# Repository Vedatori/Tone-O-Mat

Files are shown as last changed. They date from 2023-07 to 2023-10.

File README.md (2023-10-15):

# Tone-O-Mat V2.0 [cz]
Tone-O-Mat je analogový syntetizátor vytvořený pro Letní robotický tábor 2023 organizovaný spolkem Vědátoři. Jedná se o stavebnici založenou na 555 timeru určenou pro vzdělávání v oblasti STEM s reproduktorem nebo výstupem pro audio-jack. Stavebnice se skládá ze dvou hlavních částí - plošného spoje osazeného elektronickými součástkami a dřevěné krabičky. Tuto stavebnici účastníci tábora obdrželi k montáži. Hlavním cílem bylo zdokonalit dovednosti pájení a zručnost v práci se dřevem. Z připravených dřevěných dílů si účastníci sami sestavili a slepili krabičku. Poté se pustili do pájení všech součástek na plošný spoj. Měli možnost volit mezi tradičním pájením THT a náročnějším zapájením SMD součástek. Tento projekt byl koncipován tak, aby byl přístupný jak úplným začátečníkům v pájení, tak i těm s více zkušenostmi. Po dokončení stavebnice mohli účastníci na syntetizátoru hrát jako na malém klavírku.

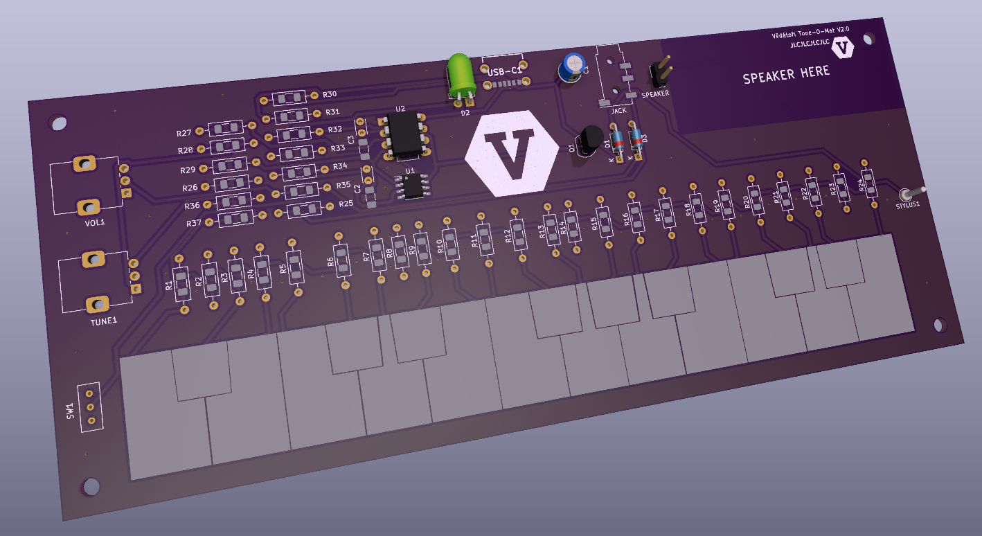
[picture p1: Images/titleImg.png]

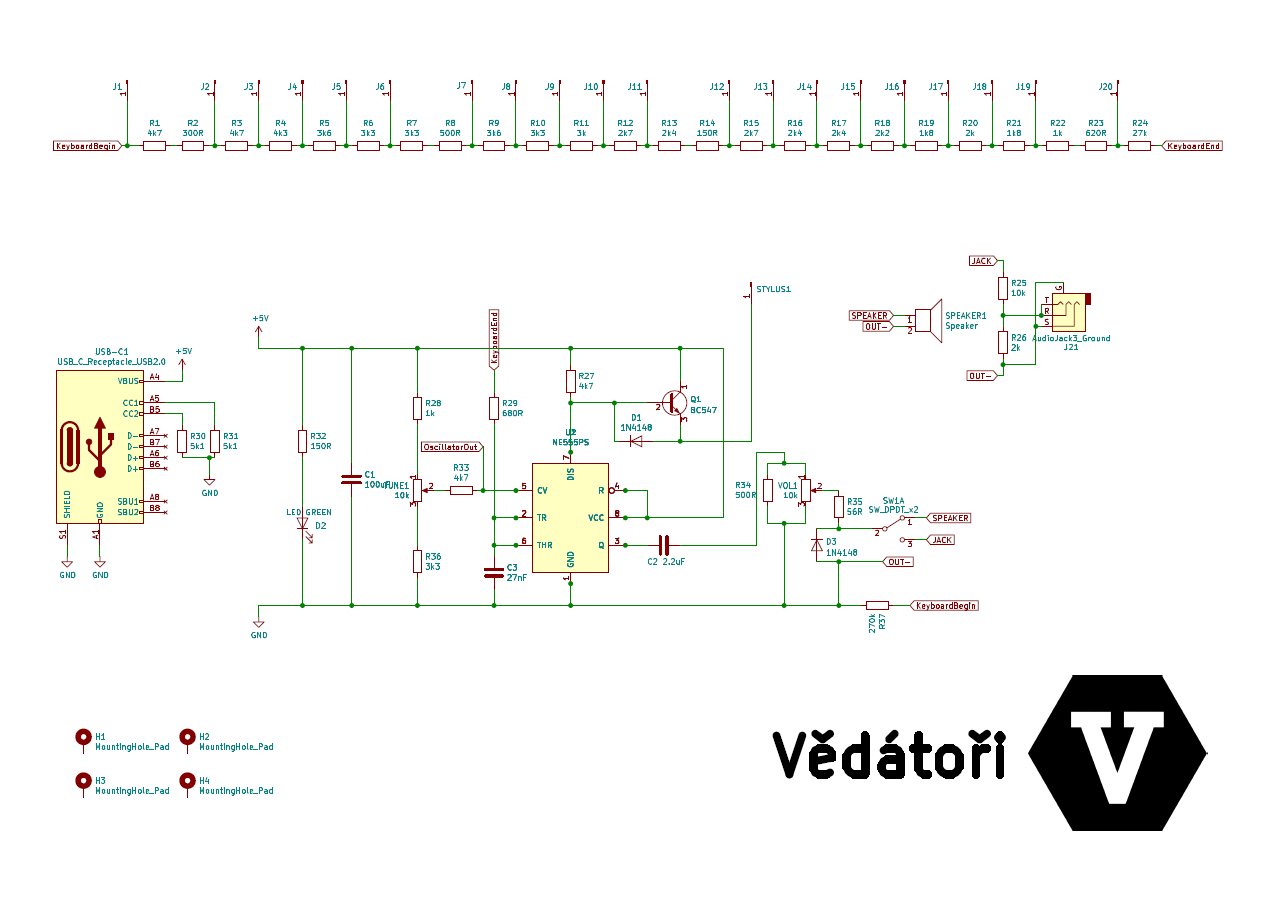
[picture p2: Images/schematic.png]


# Tone-O-Mat V2.0 [en]
Tone-O-Mat is an analog tone synthesizer designed for Summer robotics camp 2023 (cz) organized by Vědátoři team (cz). It is an electronic kit based on a 555 timer meant for STEM education, with speaker or audio-jack output. It is composed of two main parts - a printed circuit board with electronic components and a wooden enclosure. Participants at the camp received this kit for assembly. The primary objective was to enhance soldering skills and proficiency in working with wood. From the pre-cut wooden pieces, participants assembled and glued the enclosure themselves. They then proceeded to solder all the components onto the printed circuit board. They had the option to choose between traditional THT soldering and the more challenging SMD soldering. This project was designed to be accessible to both complete beginners in soldering and those with more experience. Upon completing the assembly, participants could play the synthesizer as a miniature keyboard.

## Licence
* Obsah tohoto repozitáře je sdílen pod licencí [Attribution-NonCommercial-ShareAlike 4.0 International (CC BY-NC-SA 4.0)](https://creativecommons.org/licenses/by-nc-sa/4.0/).

## License
* The contents of this repository are shared under the license [Attribution-NonCommercial-ShareAlike 4.0 International (CC BY-NC-SA 4.0)](https://creativecommons.org/licenses/by-nc-sa/4.0/).

## Source
The schematic was customised from the schematic found at https://gr33nonline.wordpress.com/2018/04/25/stylophone/

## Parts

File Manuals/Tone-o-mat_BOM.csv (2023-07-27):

Designator | Footprint | Quantity | Value | LCSC Part #
C1, C3, C5 | 1206 | 3 | 0.1uF
C10 | C_Disc_D3.0mm_W2.0mm_P2.50mm | 1 | 2.2uF
C11 | 1206 | 1 | 2.2uF
C12 | C_Disc_D3.0mm_W2.0mm_P2.50mm | 1 | 27nF
C13 | 1206 | 1 | 27nF
C2, C4, C6 | C_Disc_D3.0mm_W2.0mm_P2.50mm | 3 | 0.1uF
C7 | 1206 | 1 | 10uF
C8 | C_Disc_D3.0mm_W2.0mm_P2.50mm | 1 | 10uF
C9 | CP_Radial_D5.0mm_P2.00mm | 1 | 100uF
D1, D3 | D_DO-35_SOD27_P7.62mm_Horizontal | 2 | 1N4148
D2 | LED_D5.0mm_Horizontal_O1.27mm_Z3.0mm | 1 | LED GREEN
G1 | Vedatori_logo | 1 | LOGO
G2 | Vedatori_logo_small | 1 | LOGO
H1, H2, H3 | MountingHole_3.2mm_M3_DIN965 | 3 | MountingHole_Pad
J1, J16, J4, J9 | Tone-O-Mat-Left-Pad | 4 | Conn_01x01_Male
J10, J12, J14, J17, J19, J2, J5, J7 | Tone-O-Mat-Top-Pad | 8 | Conn_01x01_Male
J11, J13, J18, J6 | Tone-O-Mat-Middle-Pad | 4 | Conn_01x01_Male
J15, J20, J3, J8 | Tone-O-Mat-Right-Pad | 4 | Conn_01x01_Male
Q1, Q2 | TO-92_Inline | 2 | BC547
R1, R49, R5, R59, R73 | 1206 | 5 | 4k7
R10, R18 | R_Axial_DIN0207_L6.3mm_D2.5mm_P10.16mm_Horizontal | 2 | 3k6
R11, R13, R19, R53, R55, R79 | 1206 | 6 | 3k3
R12, R14, R20, R54, R56, R80 | R_Axial_DIN0207_L6.3mm_D2.5mm_P10.16mm_Horizontal | 6 | 3k3
R15 | 1206 | 1 | 499R
R16 | R_Axial_DIN0207_L6.3mm_D2.5mm_P10.16mm_Horizontal | 1 | 499R
R17, R9 | 1206 | 2 | 3k6
R2, R50, R6, R60, R74 | R_Axial_DIN0207_L6.3mm_D2.5mm_P10.16mm_Horizontal | 5 | 4k7
R21 | 1206 | 1 | 3k
R22 | R_Axial_DIN0207_L6.3mm_D2.5mm_P10.16mm_Horizontal | 1 | 3k
R23, R29 | 1206 | 2 | 2k7
R24, R30 | R_Axial_DIN0207_L6.3mm_D2.5mm_P10.16mm_Horizontal | 2 | 2k7
R25, R31, R33 | 1206 | 3 | 2k4
R26, R32, R34 | R_Axial_DIN0207_L6.3mm_D2.5mm_P10.16mm_Horizontal | 3 | 2k4
R27, R51, R71 | 1206 | 3 | 150R
R28, R52, R72 | R_Axial_DIN0207_L6.3mm_D2.5mm_P10.16mm_Horizontal | 3 | 150R
R3, R62 | R_Axial_DIN0207_L6.3mm_D2.5mm_P10.16mm_Horizontal | 2 | 300R
R35 | 1206 | 1 | 2k2
R36 | R_Axial_DIN0207_L6.3mm_D2.5mm_P10.16mm_Horizontal | 1 | 2k2
R37, R41 | 1206 | 2 | 1k8
R38, R42 | R_Axial_DIN0207_L6.3mm_D2.5mm_P10.16mm_Horizontal | 2 | 1k8
R39 | 1206 | 1 | 2k
R4, R61 | 1206 | 2 | 300R
R40 | R_Axial_DIN0207_L6.3mm_D2.5mm_P10.16mm_Horizontal | 1 | 2k
R43, R63, R77 | 1206 | 3 | 1k
R44, R64, R78 | R_Axial_DIN0207_L6.3mm_D2.5mm_P10.16mm_Horizontal | 3 | 1k
R45 | 1206 | 1 | 620R
R46 | R_Axial_DIN0207_L6.3mm_D2.5mm_P10.16mm_Horizontal | 1 | 620R
R47 | 1206 | 1 | 27k
R48 | R_Axial_DIN0207_L6.3mm_D2.5mm_P10.16mm_Horizontal | 1 | 27k
R57 | 1206 | 1 | 10k
R58 | R_Axial_DIN0207_L6.3mm_D2.5mm_P10.16mm_Horizontal | 1 | 10k
R65 | 1206 | 1 | 680R
R66 | R_Axial_DIN0207_L6.3mm_D2.5mm_P10.16mm_Horizontal | 1 | 680R
R67, R69 | 1206 | 2 | 5k1
R68, R70 | R_Axial_DIN0207_L6.3mm_D2.5mm_P10.16mm_Horizontal | 2 | 5k1
R7 | 1206 | 1 | 4k3
R75 | 1206 | 1 | 56R
R76 | R_Axial_DIN0207_L6.3mm_D2.5mm_P10.16mm_Horizontal | 1 | 56R
R8 | R_Axial_DIN0207_L6.3mm_D2.5mm_P10.16mm_Horizontal | 1 | 4k3
R81 | 1206 | 1 | 270k
R82 | R_Axial_DIN0207_L6.3mm_D2.5mm_P10.16mm_Horizontal | 1 | 270k
SP1 | PinHeader_1x02_P2.54mm_Vertical | 1 | Speaker
STYLUS | Pin_D1.3mm_L11.0mm | 1 | Conn_01x01_Male
TUNE, VOL | Potentiometer_Alps_RK09K_Single_Vertical | 2 | 10k
U1 | DIP-8_W7.62mm_LongPads | 1 | NE555PS
U2 | SOIC-8_3.9x4.9mm_P1.27mm | 1 | NE555PS
USB-C | USB_C_Right_Angle | 1 | USB_C_Receptacle_USB2.0
VBR | SwitchMini | 1 | VIBRATO

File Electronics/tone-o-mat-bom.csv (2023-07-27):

ID | Part number | Package | Quantity | Value | In cart
21 | C1,C7,C5,C3 | C_1206_3216Metric_Pad1.33x1.80mm_HandSolder | 4 | 0.1uF
32 | C6,C8,C2,C4 | C_Disc_D3.0mm_W2.0mm_P2.50mm | 4 | 0.1uF
63 | C9 | CP_Radial_D5.0mm_P2.00mm | 1 | 100uF
19 | R78,R28 | R_Axial_DIN0207_L6.3mm_D2.5mm_P10.16mm_Horizontal | 2 | 150R
41 | R77,R27 | R_1206_3216Metric_Pad1.30x1.75mm_HandSolder | 2 | 150R
8 | R62,R50,R56,R54,R52,R44,R60 | R_Axial_DIN0207_L6.3mm_D2.5mm_P10.16mm_Horizontal | 7 | 1k
26 | R61,R55,R59,R51,R53,R43,R49 | R_1206_3216Metric_Pad1.30x1.75mm_HandSolder | 7 | 1k
56 | VOL | Potentiometer_Alps_RK09K_Single_Vertical | 1 | 1k
33 | R38,R42 | R_Axial_DIN0207_L6.3mm_D2.5mm_P10.16mm_Horizontal | 2 | 1k8
47 | R37,R41 | R_1206_3216Metric_Pad1.30x1.75mm_HandSolder | 2 | 1k8
16 | D2,D1 | D_DO-35_SOD27_P7.62mm_Horizontal | 2 | 1N4148
6 | C11 | C_1206_3216Metric_Pad1.33x1.80mm_HandSolder | 1 | 2.2uF
28 | C10 | C_Disc_D3.0mm_W2.0mm_P2.50mm | 1 | 2.2uF
43 | R75 | R_1206_3216Metric_Pad1.30x1.75mm_HandSolder | 1 | 270k
49 | R76 | R_Axial_DIN0207_L6.3mm_D2.5mm_P10.16mm_Horizontal | 1 | 270k
35 | R47 | R_1206_3216Metric_Pad1.30x1.75mm_HandSolder | 1 | 27k
36 | R48 | R_Axial_DIN0207_L6.3mm_D2.5mm_P10.16mm_Horizontal | 1 | 27k
24 | C12 | C_Disc_D3.0mm_W2.0mm_P2.50mm | 1 | 27nF
64 | C13 | C_1206_3216Metric_Pad1.33x1.80mm_HandSolder | 1 | 27nF
48 | R39 | R_1206_3216Metric_Pad1.30x1.75mm_HandSolder | 1 | 2k
53 | R40 | R_Axial_DIN0207_L6.3mm_D2.5mm_P10.16mm_Horizontal | 1 | 2k
13 | R36 | R_Axial_DIN0207_L6.3mm_D2.5mm_P10.16mm_Horizontal | 1 | 2k2
30 | R35 | R_1206_3216Metric_Pad1.30x1.75mm_HandSolder | 1 | 2k2
14 | R33,R25,R31 | R_1206_3216Metric_Pad1.30x1.75mm_HandSolder | 3 | 2k4
38 | R32,R26,R34 | R_Axial_DIN0207_L6.3mm_D2.5mm_P10.16mm_Horizontal | 3 | 2k4
22 | R24,R30 | R_Axial_DIN0207_L6.3mm_D2.5mm_P10.16mm_Horizontal | 2 | 2k7
58 | R23,R29 | R_1206_3216Metric_Pad1.30x1.75mm_HandSolder | 2 | 2k7
18 | R4 | R_1206_3216Metric_Pad1.30x1.75mm_HandSolder | 1 | 300R
54 | R3 | R_Axial_DIN0207_L6.3mm_D2.5mm_P10.16mm_Horizontal | 1 | 300R
51 | R22 | R_Axial_DIN0207_L6.3mm_D2.5mm_P10.16mm_Horizontal | 1 | 3k
61 | R21 | R_1206_3216Metric_Pad1.30x1.75mm_HandSolder | 1 | 3k
23 | R19,R11,R13,R73 | R_1206_3216Metric_Pad1.30x1.75mm_HandSolder | 4 | 3k3
40 | R74,R14,R12,R20 | R_Axial_DIN0207_L6.3mm_D2.5mm_P10.16mm_Horizontal | 4 | 3k3
12 | R17,R9 | R_1206_3216Metric_Pad1.30x1.75mm_HandSolder | 2 | 3k6
17 | R10,R18 | R_Axial_DIN0207_L6.3mm_D2.5mm_P10.16mm_Horizontal | 2 | 3k6
55 | R7 | R_1206_3216Metric_Pad1.30x1.75mm_HandSolder | 1 | 4k3
59 | R8 | R_Axial_DIN0207_L6.3mm_D2.5mm_P10.16mm_Horizontal | 1 | 4k3
7 | R70,R58,R6,R2 | R_Axial_DIN0207_L6.3mm_D2.5mm_P10.16mm_Horizontal | 4 | 4k7
10 | TUNE | Potentiometer_Alps_RK09K_Single_Vertical | 1 | 4k7
25 | R1,R69,R57,R5 | R_1206_3216Metric_Pad1.30x1.75mm_HandSolder | 4 | 4k7
52 | R15 | R_1206_3216Metric_Pad1.30x1.75mm_HandSolder | 1 | 500R
57 | R16 | R_Axial_DIN0207_L6.3mm_D2.5mm_P10.16mm_Horizontal | 1 | 500R
39 | R72 | R_Axial_DIN0207_L6.3mm_D2.5mm_P10.16mm_Horizontal | 1 | 56R
46 | R71 | R_1206_3216Metric_Pad1.30x1.75mm_HandSolder | 1 | 56R
20 | R68,R66 | R_Axial_DIN0207_L6.3mm_D2.5mm_P10.16mm_Horizontal | 2 | 5k1
34 | R65,R67 | R_1206_3216Metric_Pad1.30x1.75mm_HandSolder | 2 | 5k1
29 | R45 | R_1206_3216Metric_Pad1.30x1.75mm_HandSolder | 1 | 620R
60 | R46 | R_Axial_DIN0207_L6.3mm_D2.5mm_P10.16mm_Horizontal | 1 | 620R
31 | R63 | R_1206_3216Metric_Pad1.30x1.75mm_HandSolder | 1 | 680R
42 | R64 | R_Axial_DIN0207_L6.3mm_D2.5mm_P10.16mm_Horizontal | 1 | 680R
44 | Q1,Q2 | TO-92_Inline | 2 | BC547
37 | D3 | LED_D5.0mm_Horizontal_O1.27mm_Z3.0mm | 1 | LED GREEN
1 | U1 | DIP-8_W7.62mm_LongPads | 1 | NE555PS
2 | U2 | SOIC-8_3.9x4.9mm_P1.27mm | 1 | NE555PS
3 | USB-C | USB_C_Right_Angle | 1 | USB_C_Receptacle_USB2.0
5 | VBR | SwitchMini | 1 | VIBRATO
- | SPEAKER | Speaker | 1 | -

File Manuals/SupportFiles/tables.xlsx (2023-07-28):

Tabulka 1 |  | Tabulka 2
Číslo rezistoru | Hodnota | Kondenzátor | Hodnota
R11, R13, R19, R53, R55, R79 | 3k3 | C1, C3, C5 | 100nF
R1, R49, R5, R59, R73 | 4k7 | C11 | 2.2uF
R43, R63, R77 | 1k | C13 | 27nF
R25, R31, R33 | 2k4 | C7 | 10uF
R27, R51, R71 | 150R
R17, R9 | 3k6
R23, R29 | 2k7
R37, R41 | 1k8
R3, R61 | 300R
R15 | 500R
R21 | 3k
R35 | 2k2
R39 | 2k
R45 | 620R
R47 | 27k
R57 | 10k
R65 | 680R
R67 | 5k1
R7 | 4k3
R75 | 56R
R81 | 270k

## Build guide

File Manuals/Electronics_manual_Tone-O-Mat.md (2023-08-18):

V tomto dokumentu je uveden návod na zapájení elektronického piána Tone-O-Mat.
Pro tento návod si zavedeme následující pojmy:
* DPS (Deska Plošných Spojů) - Laminátová deska pokrytá elektricky vodivými měděnými cestami, na kterou budeme nyní pájet součástky.
* SMD (Surface Mount Device) - Tzv. bezvývodové elektronické součástky, které mají krátké nožičky. Tyto součástky jsou připájeny k DPS pouze z jedné strany. Tyto součástky byly osazevy strojově při výrobě DPS.
* THT (Through-hole Technology) - Tzv. vývodové elekotronické součástky, které mají dlouhé nožičky. Tyto nožičky jsou před zapájením součástky prostrčeny skrz otvory v DPS.

___
# Obsah
* [Přichystání desky](#prep)
* [Osazení rezistorů](#rezistors)
* [Osazení keramických kondenzátorů](#capacitors)
* [Osazení 555 timeru](#555timer)
* [Osazení diod](#diodes)
* [Osazení tranzistorů](#transistors)
* [Osazení LED diody](#led)
* [Osazení USB-C konektoru](#usb)
* [Osazení elektrolytického kondenzátoru](#electrolyticCapacitor)
* [Osazení vypínače](#switch)
* [Osazení potenciometrů](#potentiometers)
* [Osazení reproduktoru](#speaker)
* [Stylus](#stylus)
___

<!-- _________________________________________________________________ -->
# <a name = prep>Přichystání desky</a>
## Potřebujeme:
* Desku plošných spojů
* Papírovou nebo jinou maskovací pásku

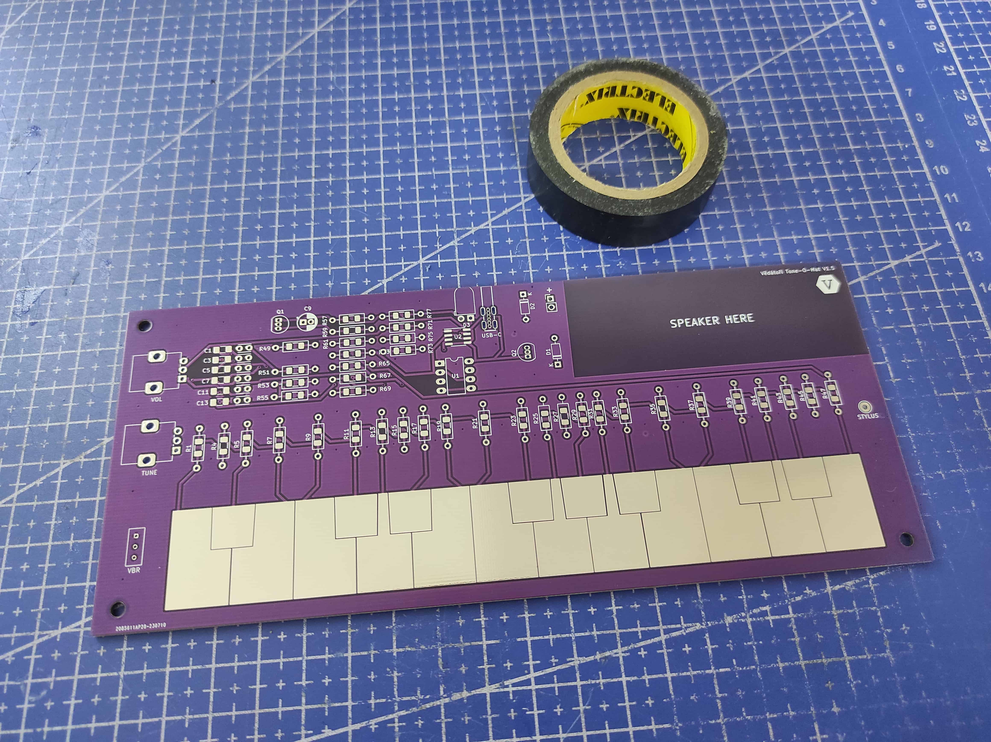
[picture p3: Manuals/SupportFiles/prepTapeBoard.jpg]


## Postup:
Přelepte klávesnici páskou, aby se na ni při pájení nedostal cín.
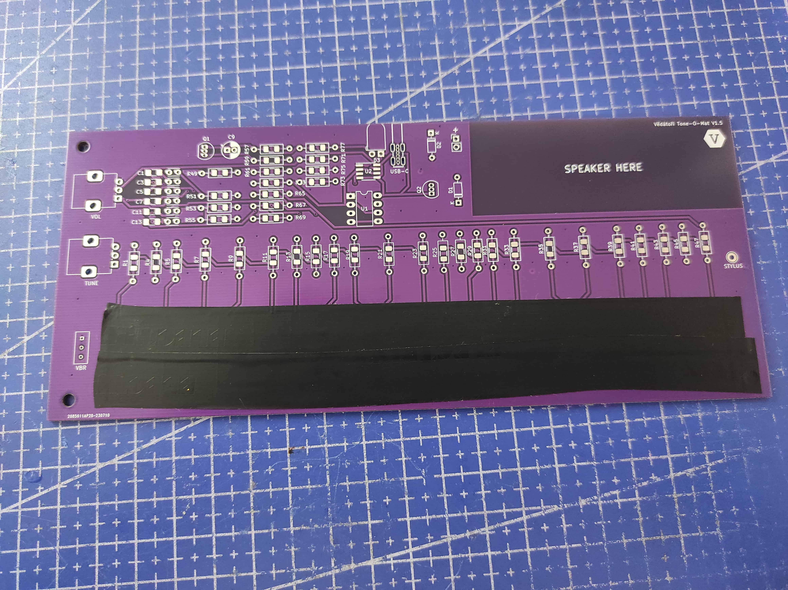
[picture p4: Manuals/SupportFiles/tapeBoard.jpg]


# <a name = rezistors>Osazení rezistorů</a>
## Potřebujeme:
* Desku plošných spojů
* Všechny hodnoty rezistorů v tabulce níže

<!-------------- Table 1 ------------>
| Číslo rezistoru | Hodnota | Obrázek |
|---:|:---:|:---:|
| R11, R13, R19, R53, R55, R79 | 3k3 |  |
| R1, R5, R49, R59, R73 | 4k7 |  |
| R43, R63, R77 | 1k |  |
| R25, R31, R33 | 2k4 |  |
| R27, R51, R71 | 150R |  |
| R3, R61 | 300R |  |
| R9, R17 | 3k6 |  |
| R23, R29 | 2k7 |  |
| R37, R41 | 1k8 |  |
| R67, R69 | 5k1 |  |
| R7 | 4k3 |  |
| R15 | 500R |  |
| R21 | 3k |  |
| R35 | 2k2 |  |
| R39 | 2k |  |
| R45 | 620R |  |
| R47 | 27k |  |
| R57 | 10k |  |
| R65 | 680R |  |
| R75 | 56R |  |
| R81 | 270k |  |

\(Images made with help of software at https://www.digikey.com/en/resources/conversion-calculators/conversion-calculator-resistor-color-code\)

Tip pro ty, kteří pájí SMD rezistory: Na rezistoru je vždy číslo, které udává jeho hodnotu, nicméně poslední číslice značí počet nul na konci. To znamená že rezistor na obrázku není 512 ohmů, ale 5100 (5k1), rezistor 560 by byl 56 ohmů apod.
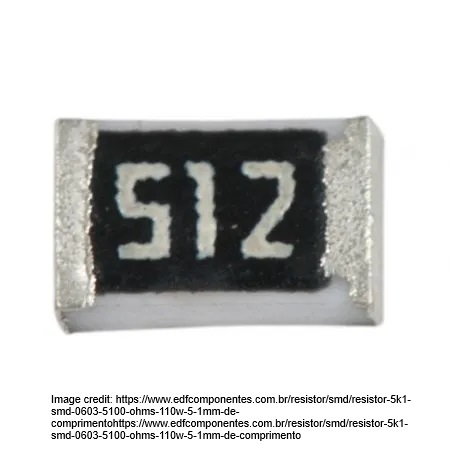
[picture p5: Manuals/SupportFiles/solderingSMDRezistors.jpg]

<!-------------------------->

## Postup:
Nyní je třeba se rozhodnout, jestli chcete osazovat THT nebo SMD součástky. Na obrázku vidíte, jak správně osadit THT nebo SMD rezistor.
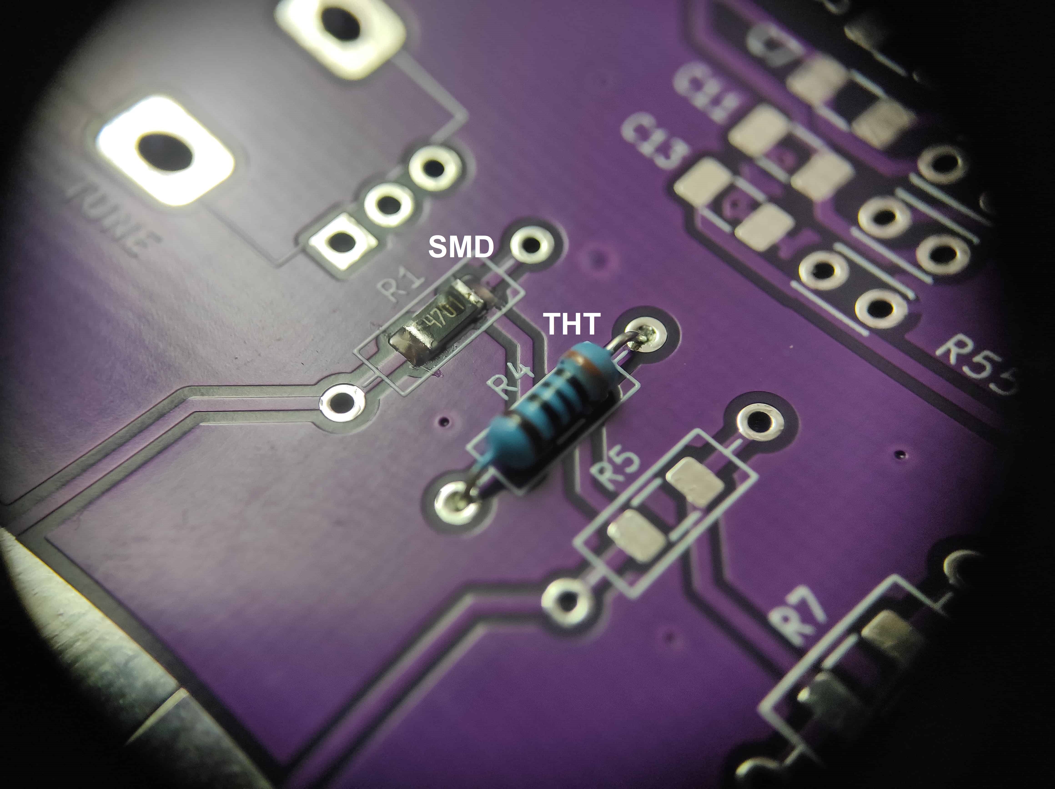
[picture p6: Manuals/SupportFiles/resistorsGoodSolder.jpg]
    
Přichystejte si THT nebo SMD rezistory.
Postupně osaďte desku odpovídajícími hodnotami rezistorů, které najdete v tabulce nahoře.
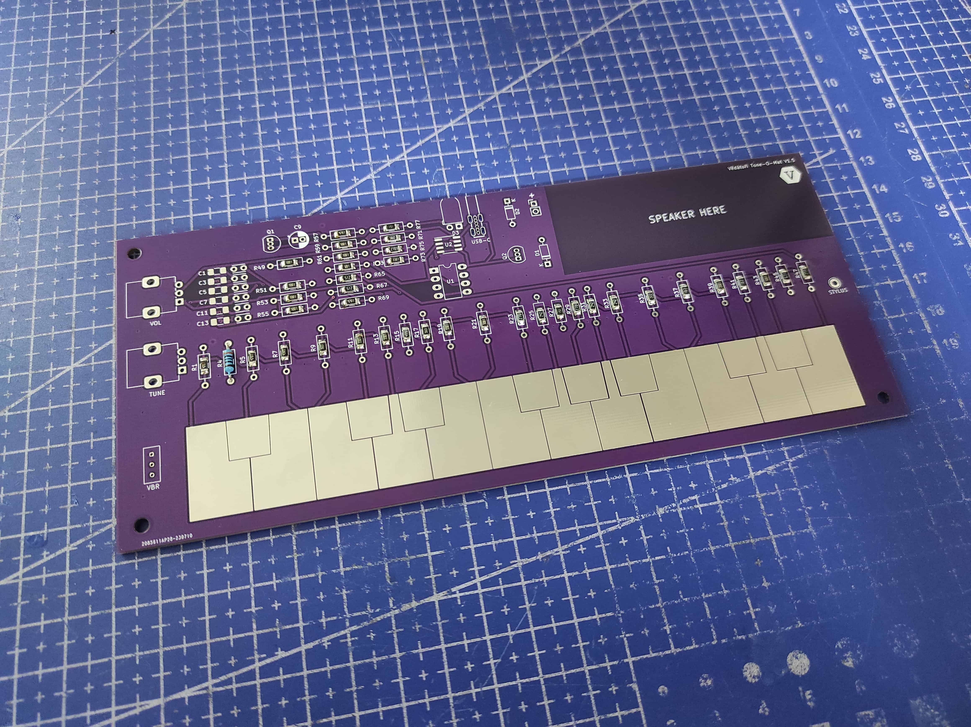
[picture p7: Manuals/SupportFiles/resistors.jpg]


# <a name = capacitors>Osazení keramických kondenzátorů</a>
## Potřebujeme:
* Desku plošných spojů
* Všechny hodnoty keramických kondenzátorů v tabulce níže

| Kondenzátor | Hodnota |
|---:|:---:|
| C1, C3, C5 | 100nF |
| C7 | 10uF |
| C11 | 2.2uF |
| C13 | 27nF |

Pro ty, co dostali stavebnici domů, jsou na následujícím obrázku popsány hodnoty kondenzátorů.
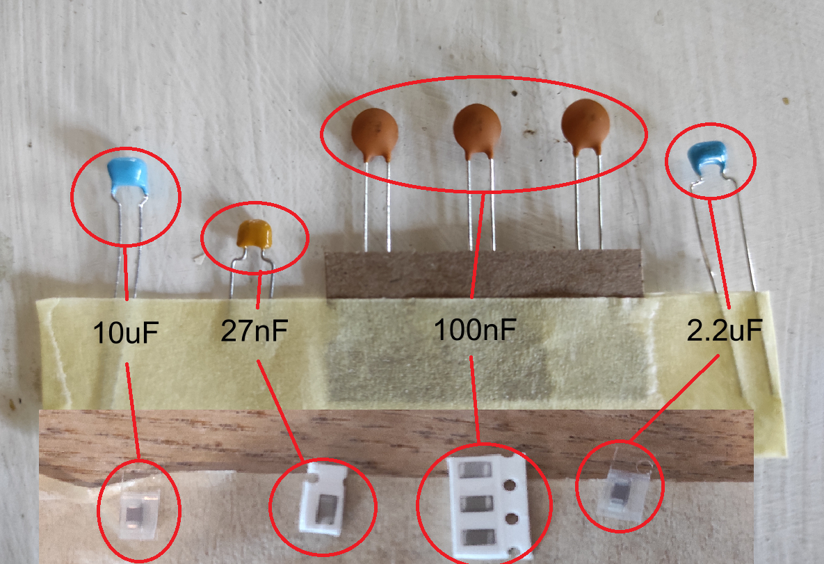
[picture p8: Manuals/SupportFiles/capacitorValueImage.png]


## Postup:
Na obrázku vidíte, jak správně osadit THT nebo SMD kondenzátor.
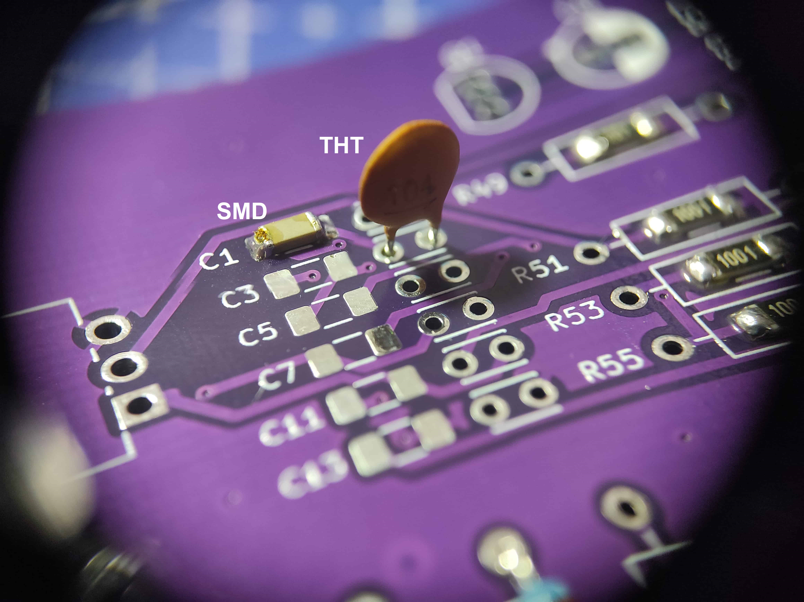
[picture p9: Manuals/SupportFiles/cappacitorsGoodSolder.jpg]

Postupně osaďte všechny kondenzátory v SMD nebo THT variantě.
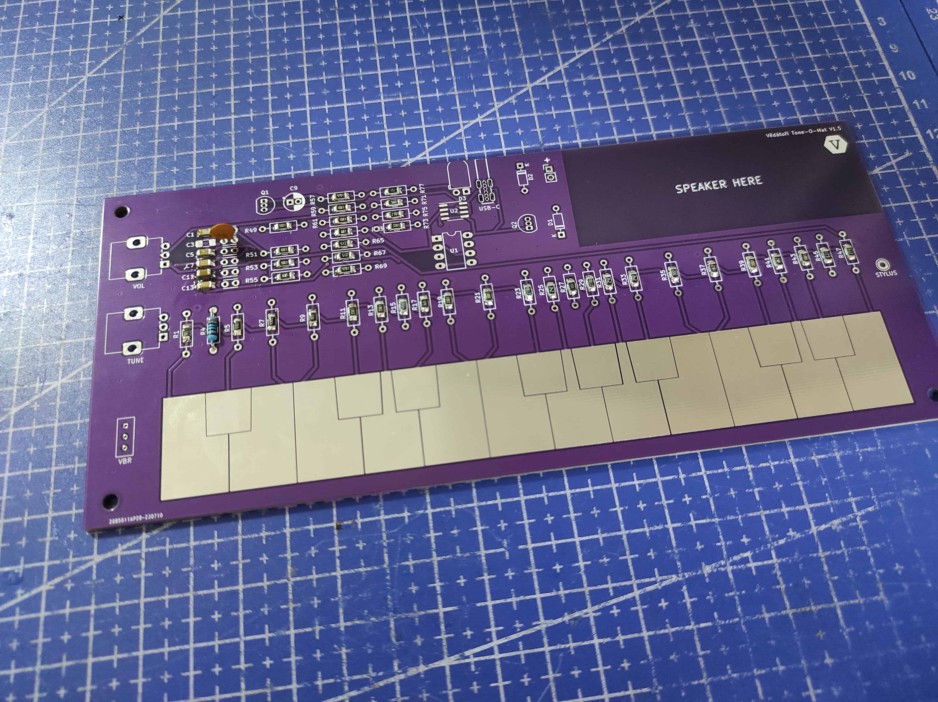
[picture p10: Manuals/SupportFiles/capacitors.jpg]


# <a name = 555timer>Osazení 555 timeru</a>
## Potřebujeme:
* Desku plošných spojů
* timer NE555 v THT nebo SMD variantě

## Postup:
Osaďte 555 timer na desku. Nezapomeňte na polaritu součástky!
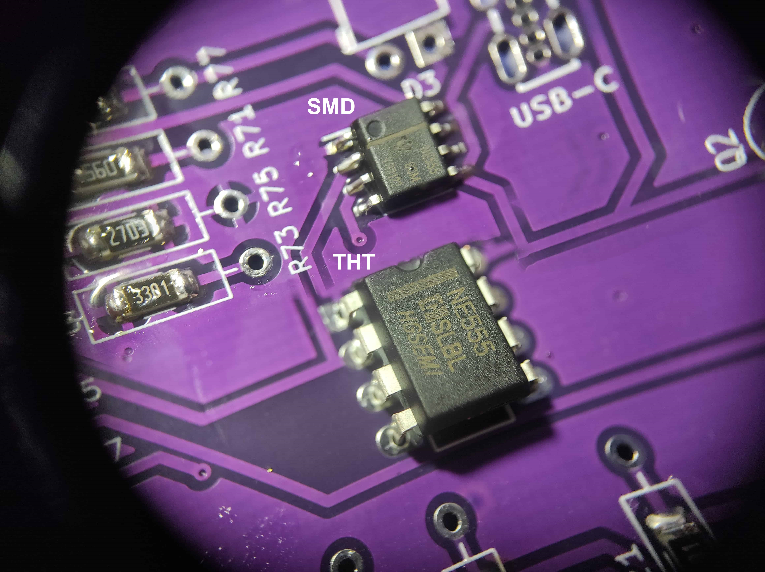
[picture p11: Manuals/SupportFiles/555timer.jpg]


# <a name = diodes>Osazení diod</a>
## Potřebujeme:
* Desku plošných spojů
* 2x dioda 1N4148

## Postup:
Osaďte obě diody. Nezapomeňte na polaritu součástky a fakt, že každá dioda směřuje jiným směrem!
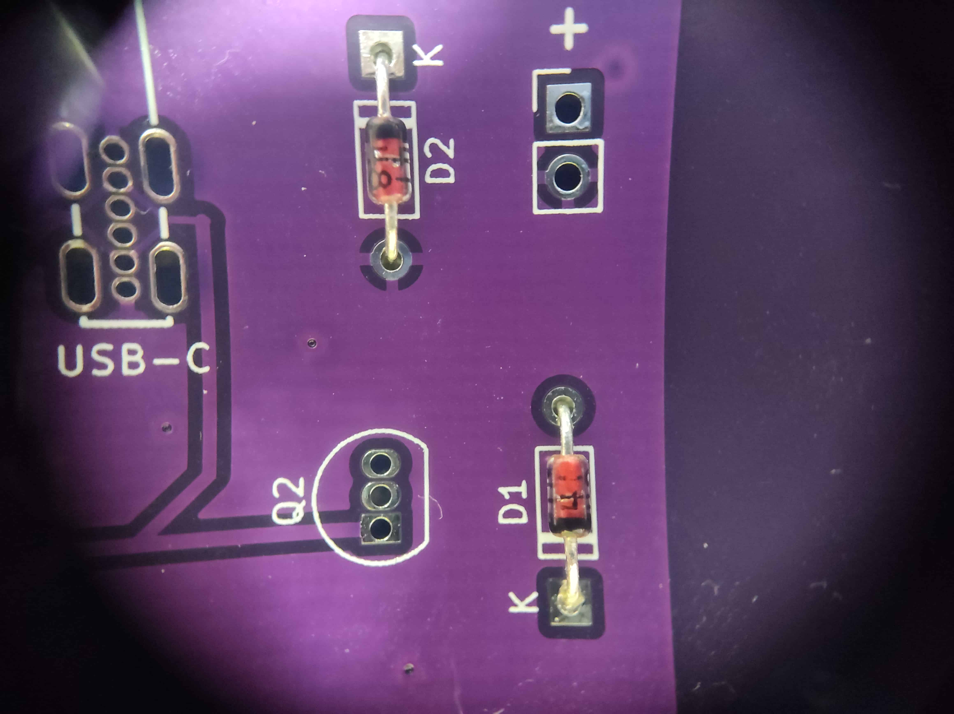
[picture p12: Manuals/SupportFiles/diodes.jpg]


# <a name = transistors>Osazení tranzistorů</a>
## Potřebujeme:
* Desku plošných spojů
* 2x tranzistor BC547

## Postup:
Osaďte oba tranzistory. Nezapomeňte na polaritu součástky a fakt, že každý tranzistor směřuje jiným směrem!
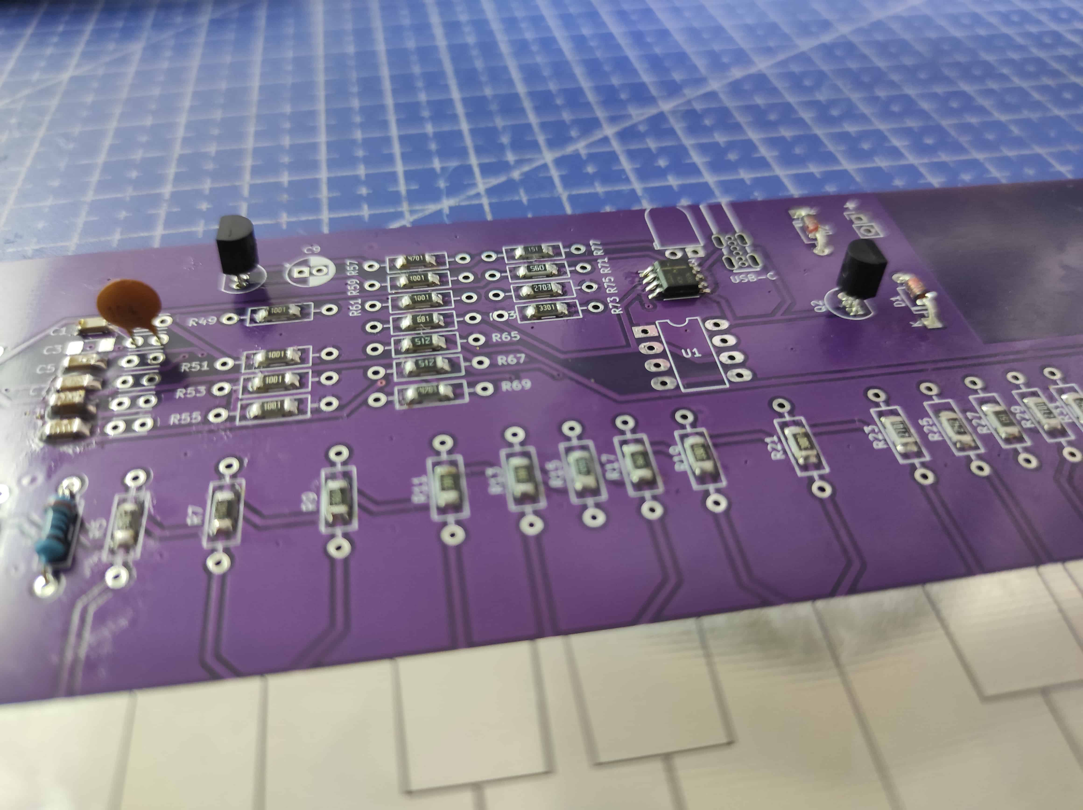
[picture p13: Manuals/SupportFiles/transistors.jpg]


# <a name = led>Osazení LED diody</a>
## Potřebujeme:
* Desku plošných spojů
* 1x zelená LED

## Postup:
Osaďte zelenou LED. Nezapomeňte na polaritu součástky (+ je vyznačeno na desce (až od verze 1.6) a je to ta delší nožička LEDky)!
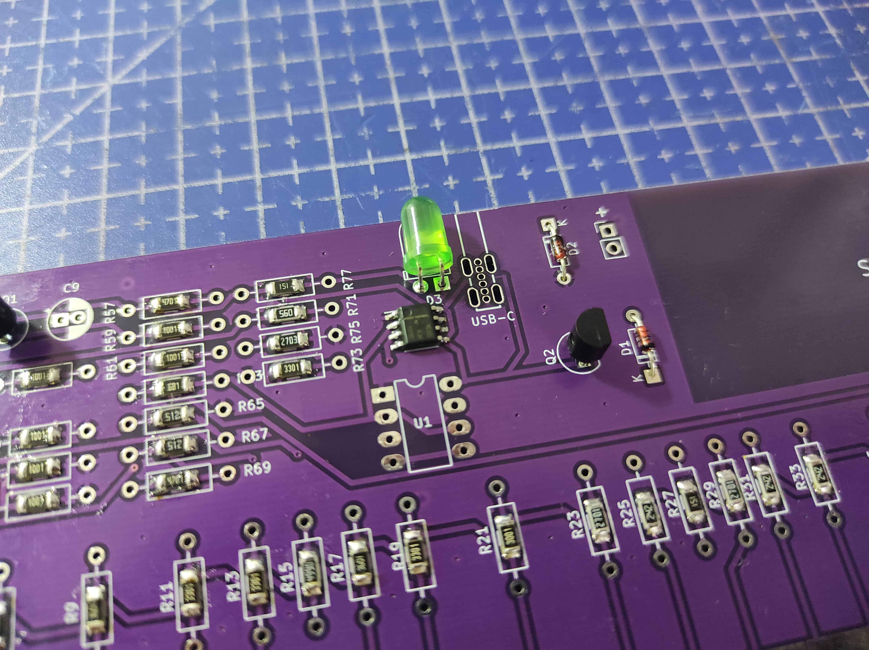
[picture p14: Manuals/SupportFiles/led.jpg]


# <a name = usb>Osazení USB-C konektoru</a>
## Potřebujeme:
* Desku plošných spojů
* 1x USB-C konektor

## Postup:
Osaďte USB-C konektor. Dbejte na malé množství cínu, piny nesmí být slité dohromady!
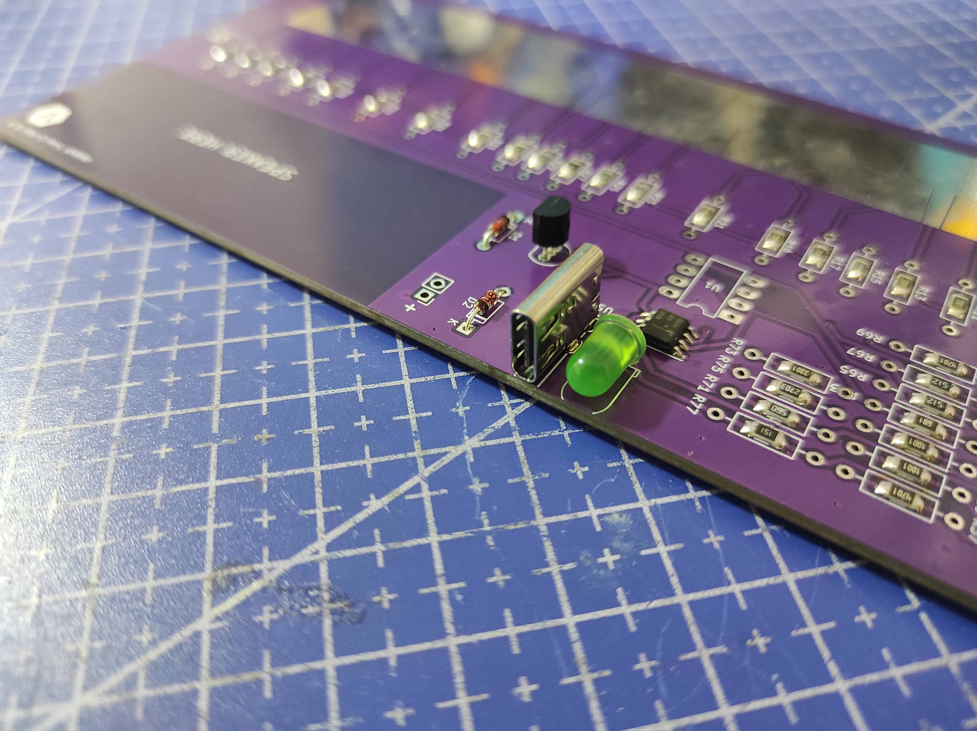
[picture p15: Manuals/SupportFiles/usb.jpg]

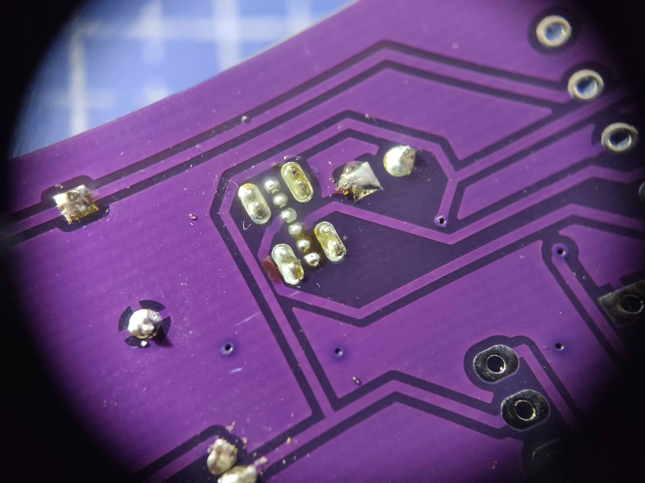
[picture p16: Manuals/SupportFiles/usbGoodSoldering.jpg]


# <a name = electrolyticCapacitor>Osazení elektrolytického kondenzátoru</a>
## Potřebujeme:
* Desku plošných spojů
* 1x elektrolytický kondenzátor 100uF

## Postup:
Osaďte elektrolytický kondenzátor. Nezapomeňte, že narozdíl od keramických kondenzátorů osazovaných předtím má tento kondenzátor polaritu (kratší nožička je -, je to vyznačeno i na obalu kondenzátoru)!
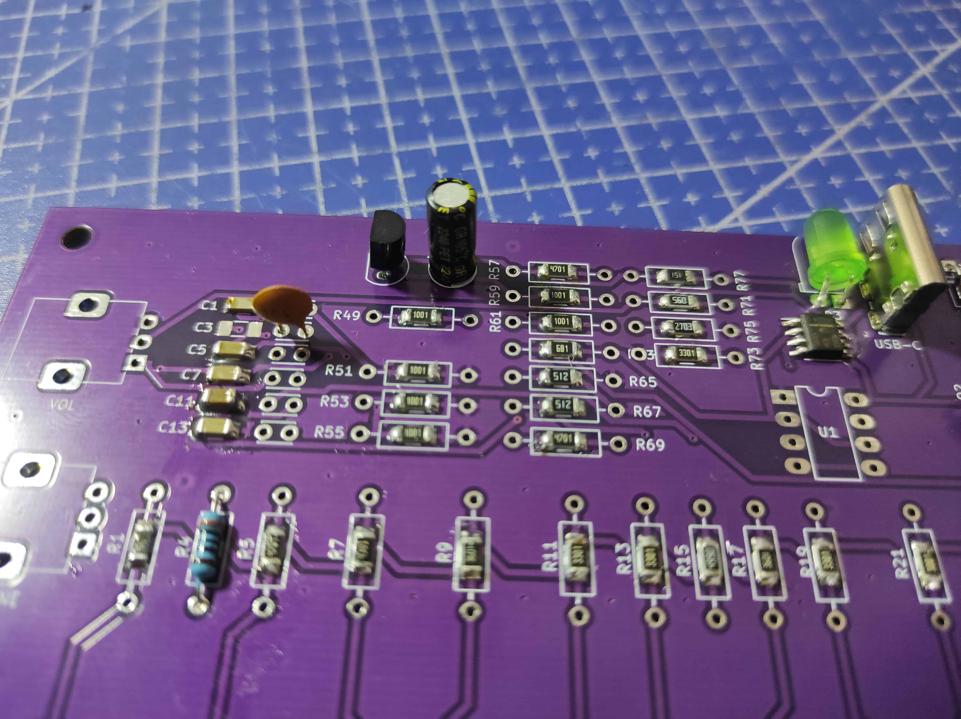
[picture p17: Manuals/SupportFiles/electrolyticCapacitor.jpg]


# <a name = switch>Osazení vypínače</a>
## Potřebujeme:
* Desku plošných spojů
* 1x vypínač

## Postup:
Osaďte vypínač. Polaritu nemá.
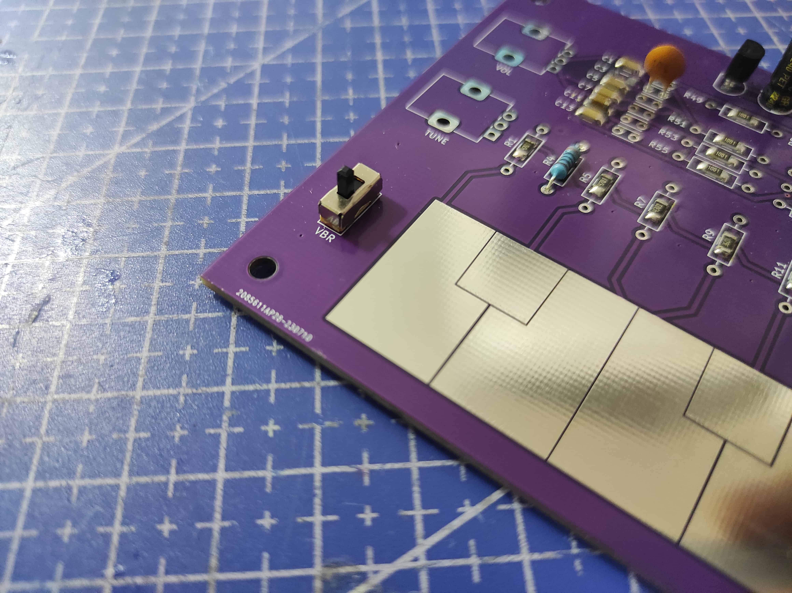
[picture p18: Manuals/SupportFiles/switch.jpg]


# <a name = potentiometers>Osazení potenciometrů</a>
## Potřebujeme:
* Desku plošných spojů
* 2x potenciometr

## Postup:
Osaďte potenciometry. Nemusíte jejich dvě větší nožičky nějak zásadně obalovat cínem, stačí malé množství.
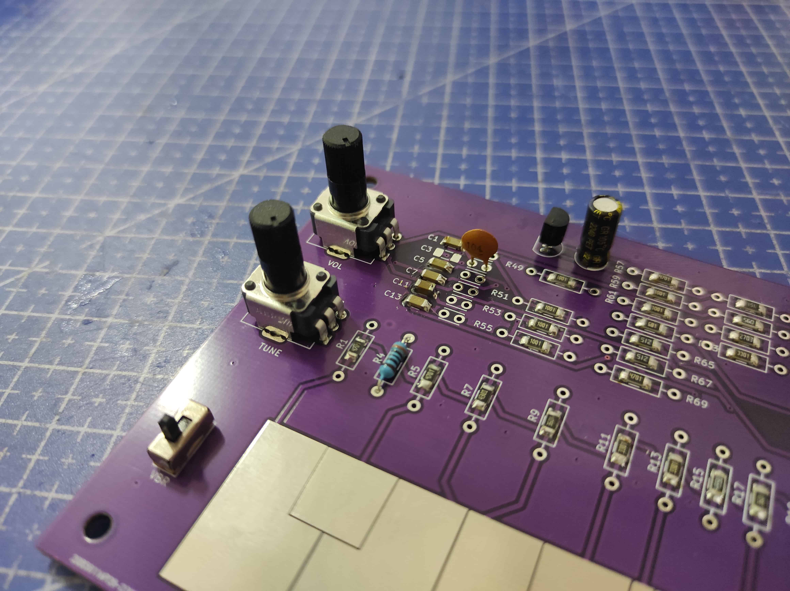
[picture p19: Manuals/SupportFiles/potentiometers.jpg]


# <a name = speaker>Osazení reproduktoru</a>
## Potřebujeme:
* Desku plošných spojů
* Reproduktor
* Cívka tenkého kabelu

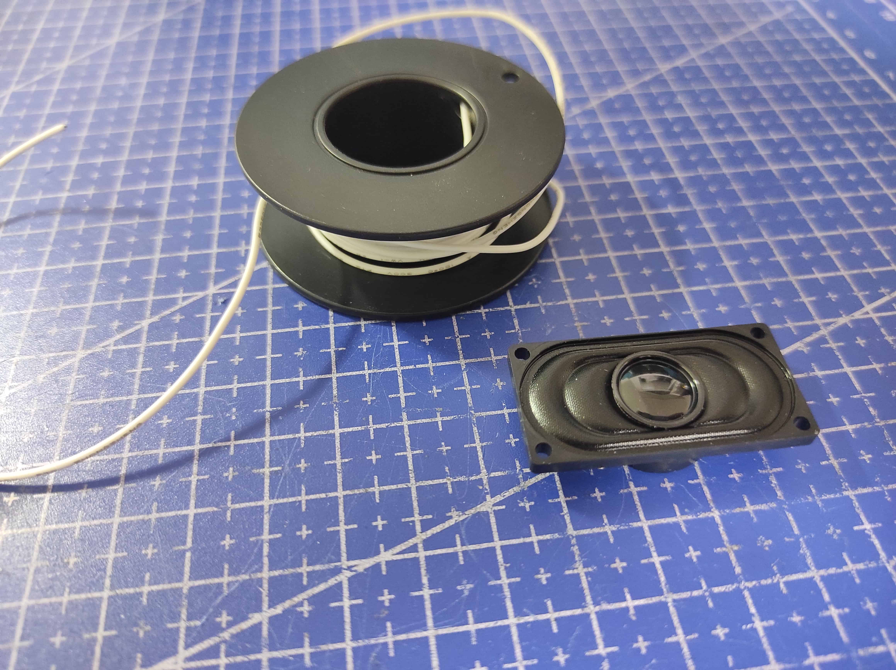
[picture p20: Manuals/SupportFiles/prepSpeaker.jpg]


## Postup:
Ustřihněte dva cca 4-5 cm dlouhé kousky kabelu a odizolujte konce. Tyto konce následně pocínujte.
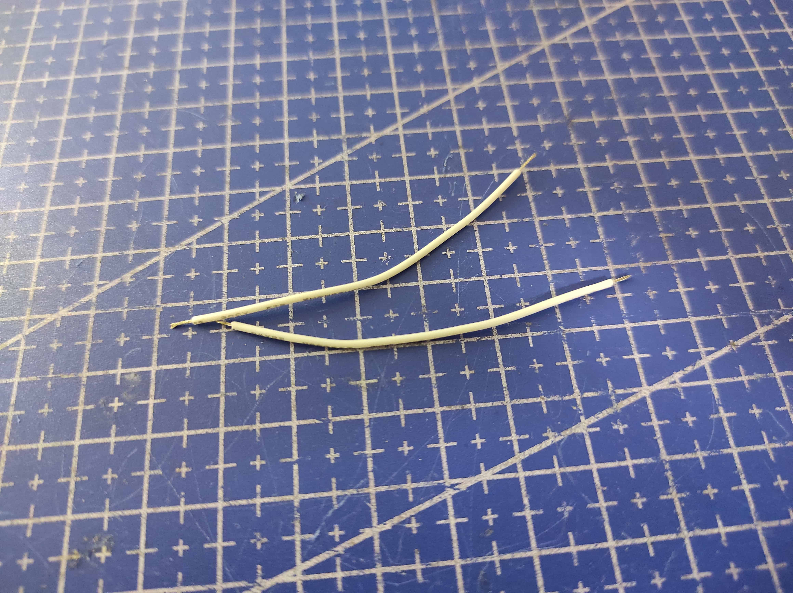
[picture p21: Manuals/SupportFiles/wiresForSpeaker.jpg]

Oba kabely připajte k reproduktoru (každý kabel k jednomu pinu).
Oba kabely připájejte do desky (i když je zde vyznačeno +, reproduktor jako takový polaritu nemá).
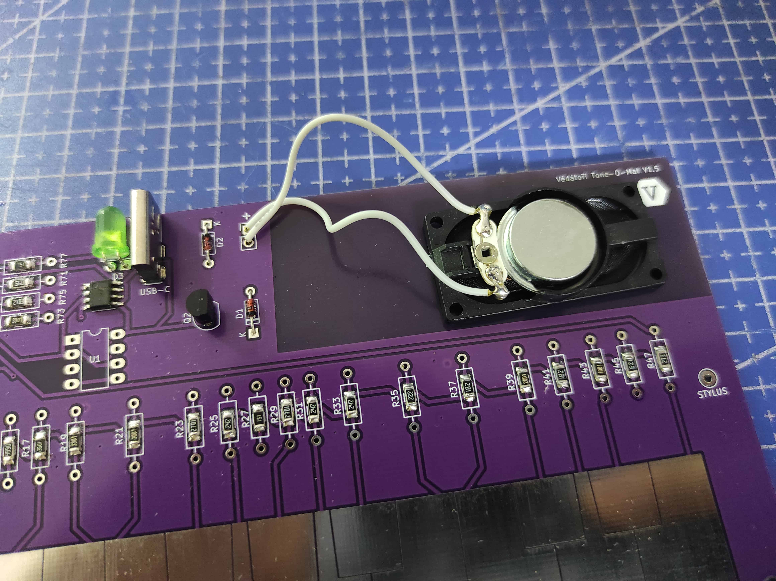
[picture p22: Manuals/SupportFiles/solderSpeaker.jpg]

Reproduktor přilepte tavnou pistolí k desce na označené místo.
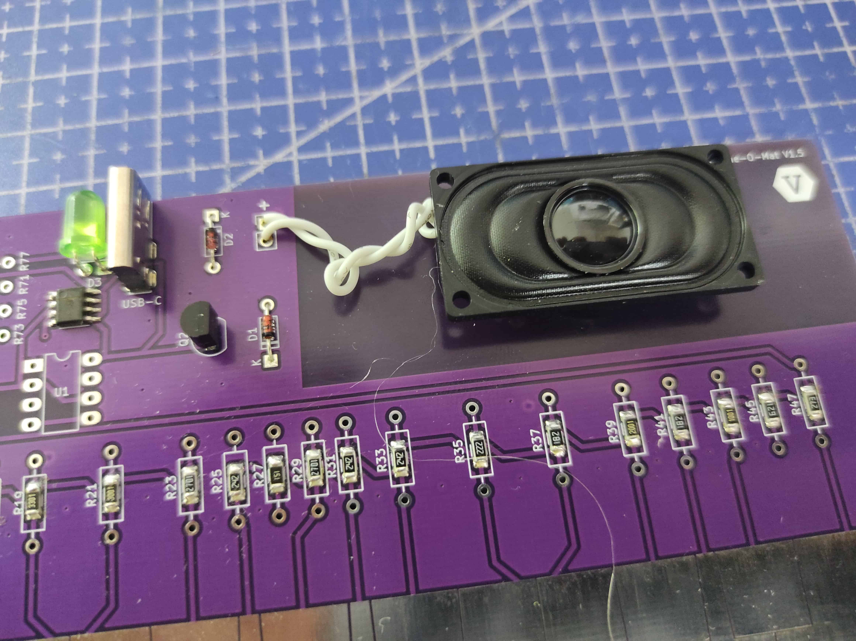
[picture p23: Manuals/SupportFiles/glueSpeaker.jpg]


# <a name = stylus>Stylus</a>
## Potřebujeme:
* Desku plošných spojů
* Kabel
* 1x Šroub M3x6
* Tělo stylusu
* Štípací kleště
* Pravítko
* Šroubovák

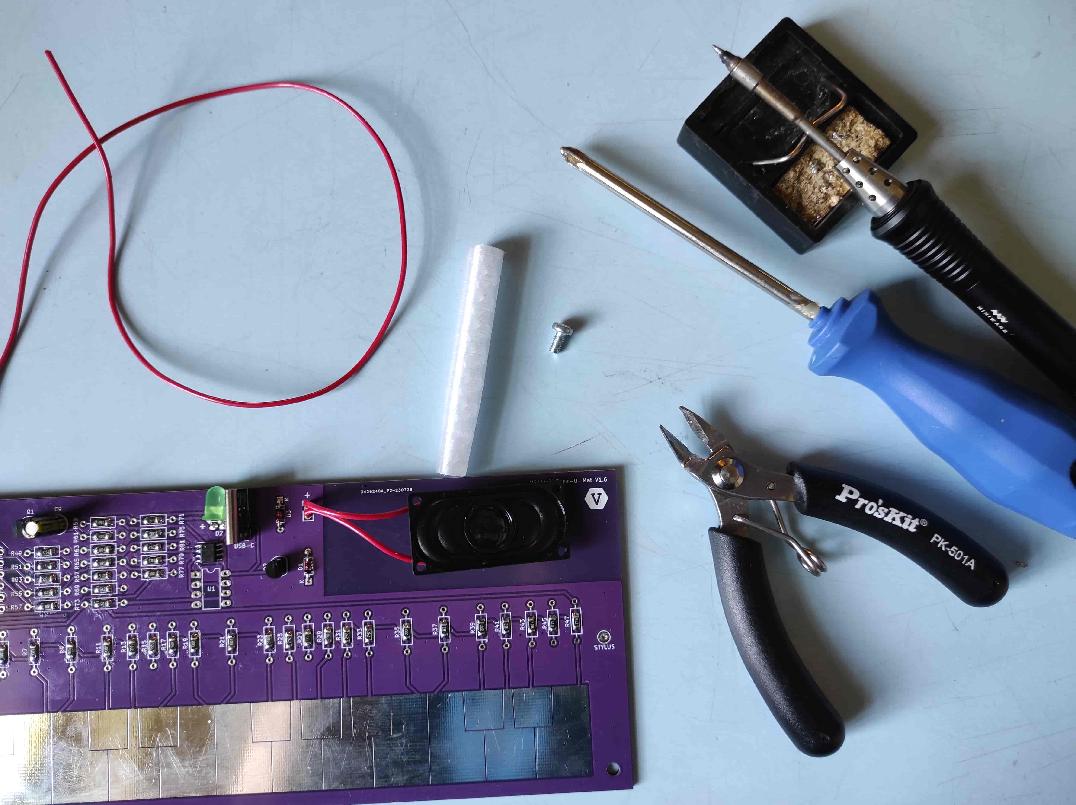
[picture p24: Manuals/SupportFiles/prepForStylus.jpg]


## Postup:
Ustřihněte cca 35 cm dlouhý kabel a odizolujte z jedné strany 3 mm, z druhé 2 cm. Kratší odizolovaný konec pocínujte.
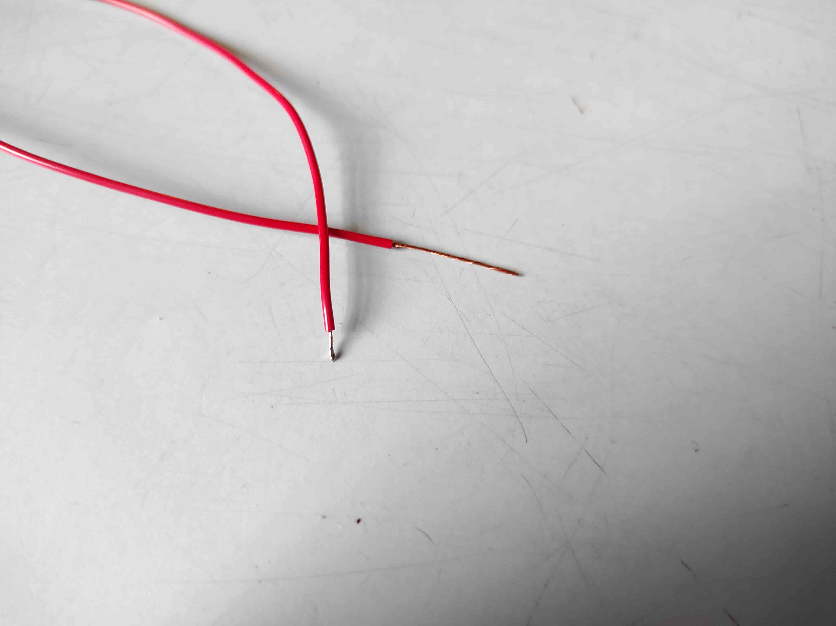
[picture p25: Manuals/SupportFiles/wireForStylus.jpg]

Delší odizolovaný konec vložte do stylusu a proveďte ho až na doraz. Poté vložte M3 šroub a omotejte kolem něho odizolovaný konec.
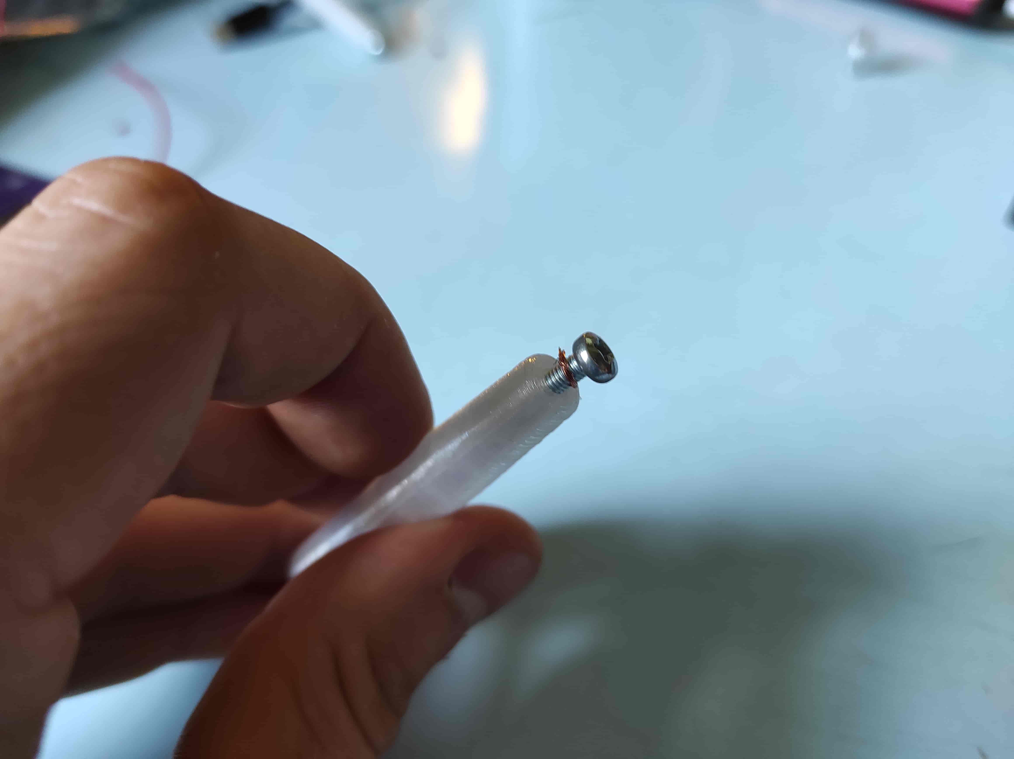
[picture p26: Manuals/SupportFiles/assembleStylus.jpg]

Šroub zašroubujte až na doraz tak, aby kolem něho byl omotaný odizolovaný konec drátu.
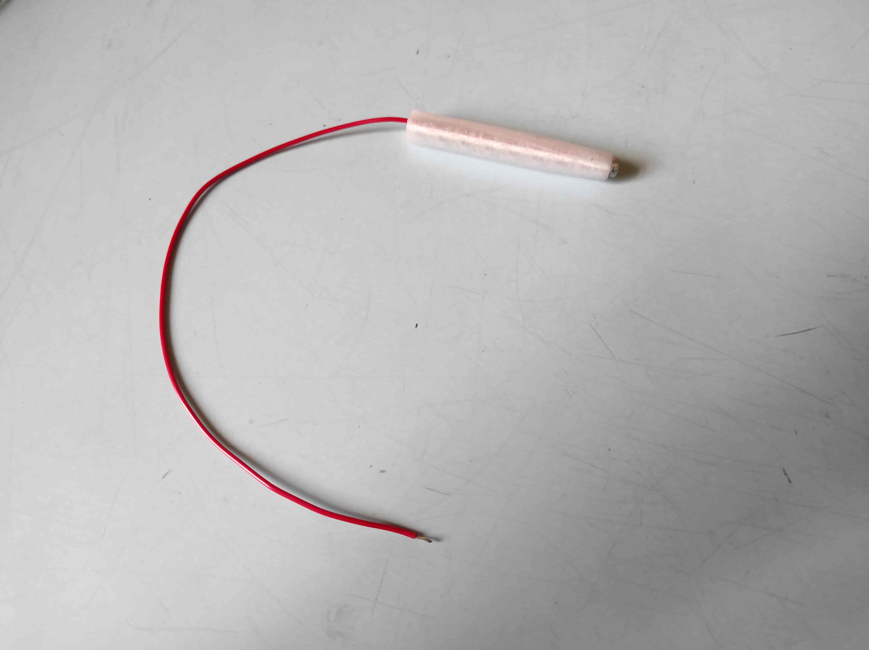
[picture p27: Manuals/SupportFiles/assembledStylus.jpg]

Hotový stylus proveďte prvně otvorem v krabičce, poté příslušnou ploškou v desce a zapájejte.
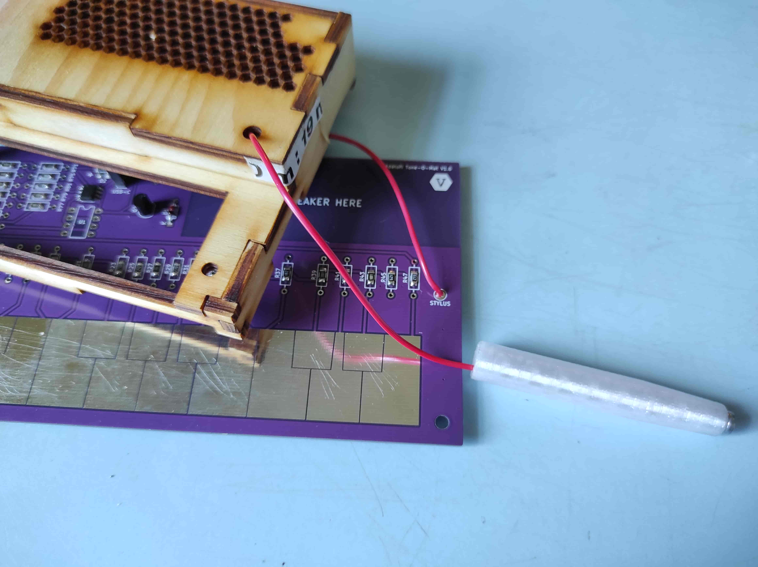
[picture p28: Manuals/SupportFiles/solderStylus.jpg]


# <a name = stylus>Kompletace</a>
## Potřebujeme:
* Spodní díl krabičky
* Vrchní část krabičky
* Osazené PCB
* 4x Šroub M3x16
* Šroubovák

## Postup:
Vložte desku do krabičky a na díry pro šrouby položte plastové spacery.

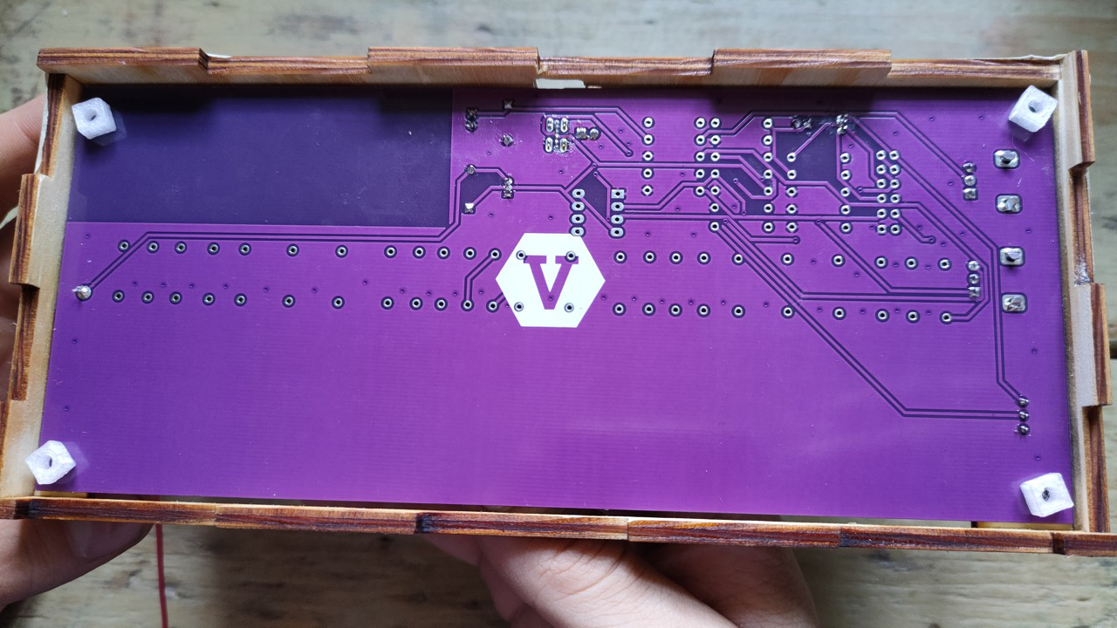
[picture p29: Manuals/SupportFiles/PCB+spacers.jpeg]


Opatrně zavřete krabičku a položte do vygravírovaných míst nožičky (nožičky s matkou patří k přední hraně desky). 
Zašroubujte zespodu krabičku pomocí dvou šroubů M3x16.

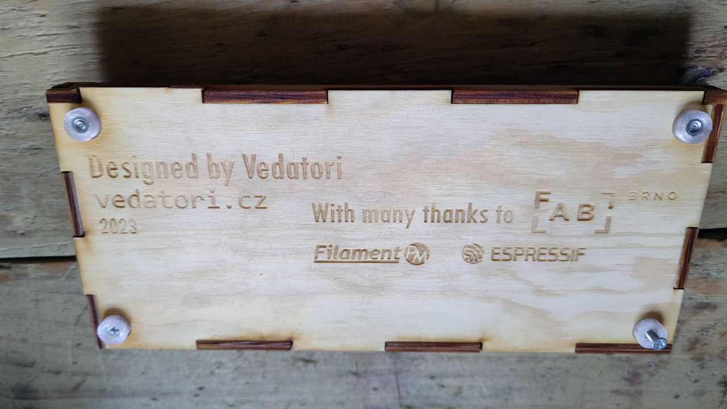
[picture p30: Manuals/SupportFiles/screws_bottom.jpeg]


Zašroubujte krabičku zvrchu pomocí dvou šroubů M3x16.

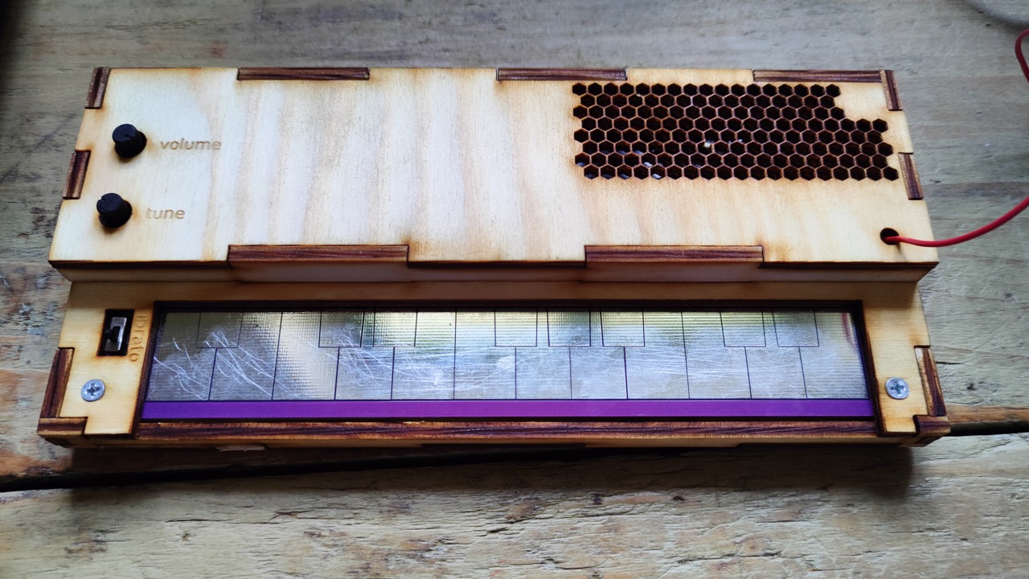
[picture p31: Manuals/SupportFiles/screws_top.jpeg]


Nasaďte 3D tištěné díly na potenciometry a přepínač.

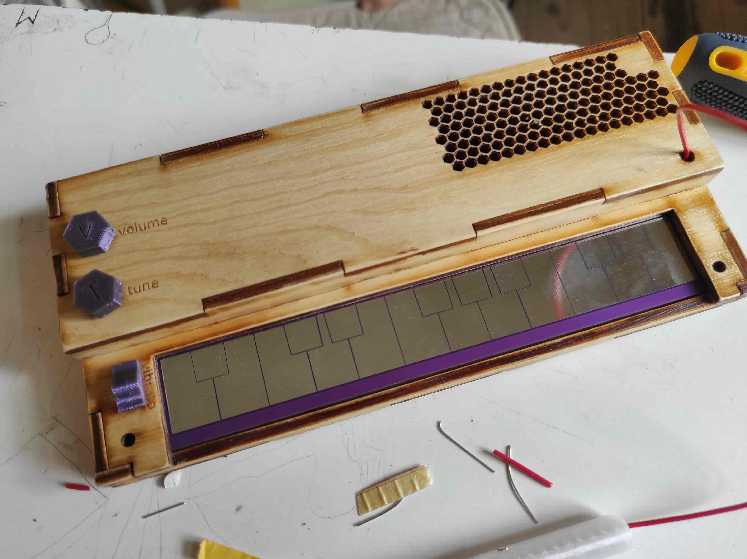
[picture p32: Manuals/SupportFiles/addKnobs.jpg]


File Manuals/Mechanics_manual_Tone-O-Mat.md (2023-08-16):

V tomto dokumentu je uveden návod na sestavení krabičky na elektronické piáno Tone-O-Mat.

# Obsah
* [Přichystání dílů](#prep)
* [Slepení krabičky](#build)
* [Lakování krabičky](#lak)

# <a name = prep>Přichystání dílů</a>
## Potřebujeme:
* Dřevěné díly
* Jemný brusný papír

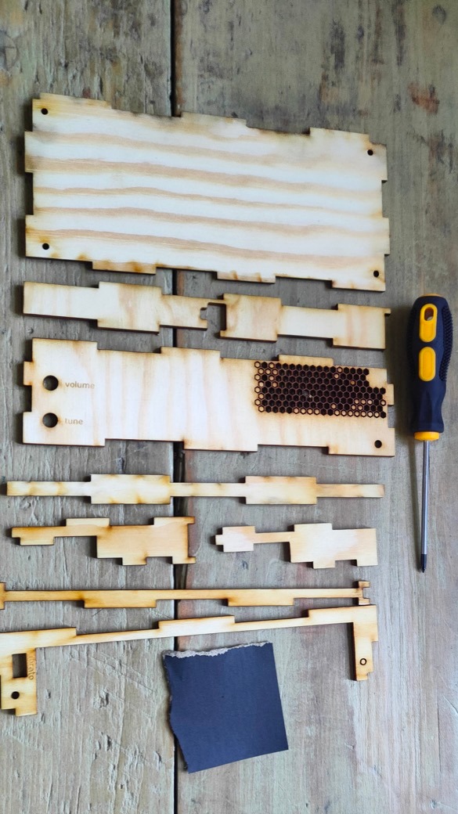
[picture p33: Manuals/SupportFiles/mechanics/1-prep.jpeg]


## Postup:
Pomocí tenkého nástroje (např. šroubovák) odstraňte zbytky ve vyřezaných otvorech.

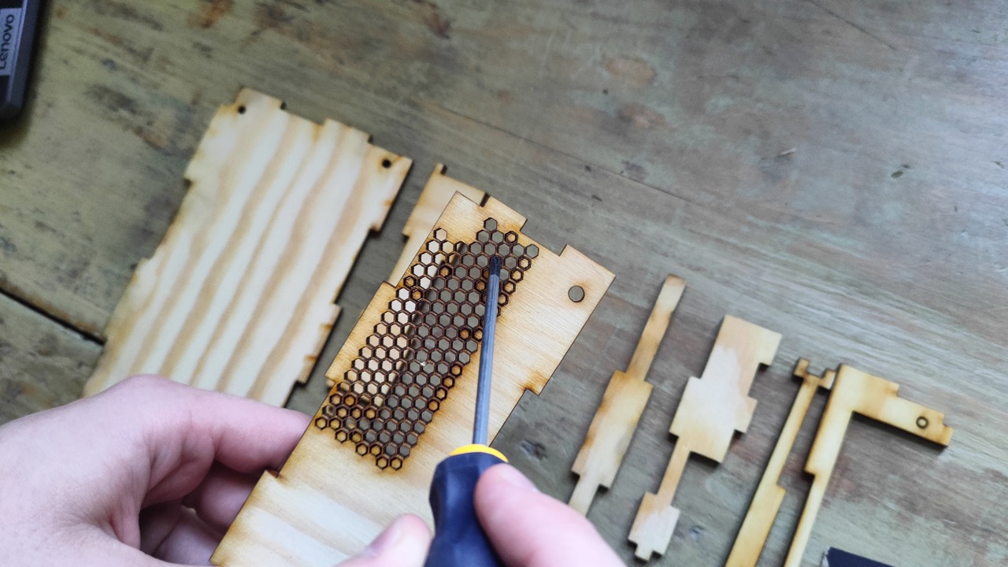
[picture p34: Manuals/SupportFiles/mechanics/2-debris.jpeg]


Jemným brusným papírem obruste pohledové plochy dřevěných dílů. Pohledové plochy jsou ty, kde je něco vygravírováno nebo ty, které jsou méně opálené od laseru. 
Po broušení si ukliďte pracovní plochu a zbavte ji dřevěného prachu z broušení.

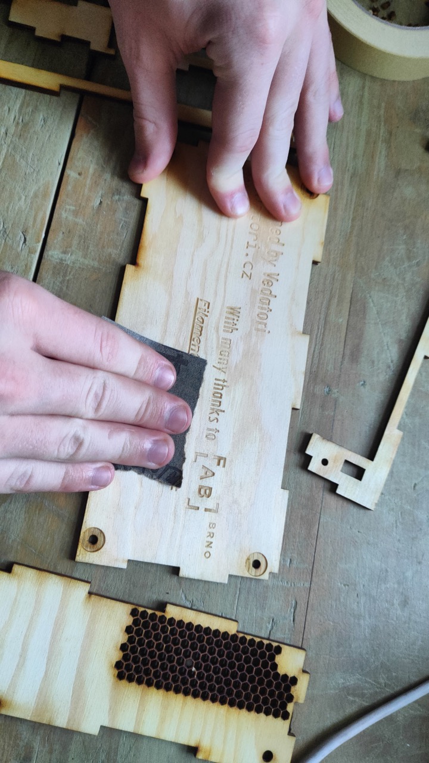
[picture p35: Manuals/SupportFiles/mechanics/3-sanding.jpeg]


Rozložte si všechny díly na pracovní plochu, tak aby odpovídali obrázku níže.

Pozor na orientaci dílů, při nesprávném otočení nepůjde krabička složit.

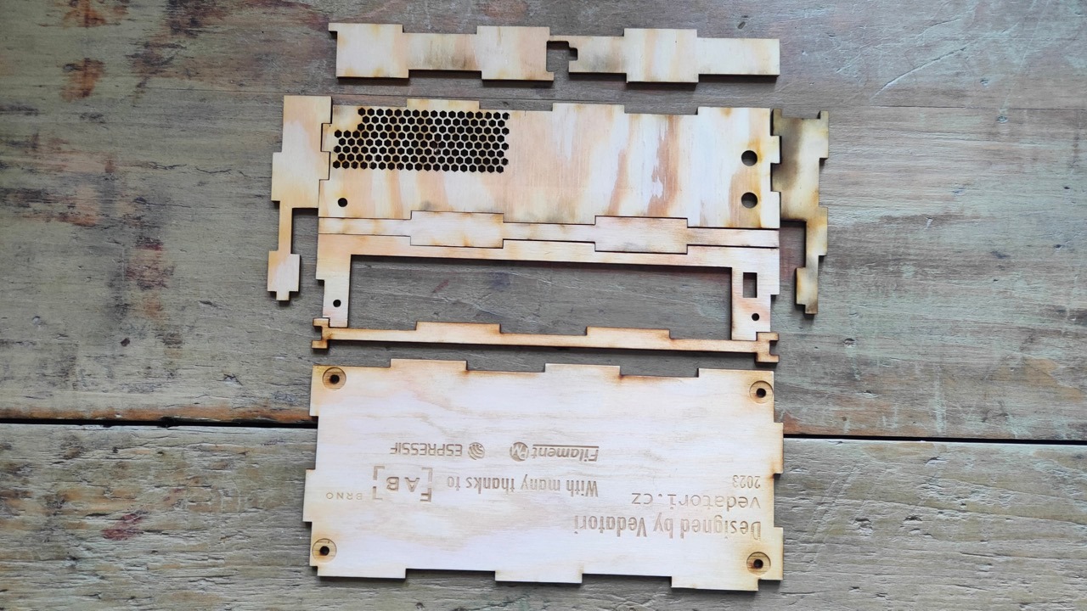
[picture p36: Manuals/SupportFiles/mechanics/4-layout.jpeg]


# <a name = build>Slepení krabičky</a>
## Potřebujeme:
* Dřevěné díly
* Tištěné díly
* 4x Matice M3
* Lepidlo Herkules
* Papírová páska

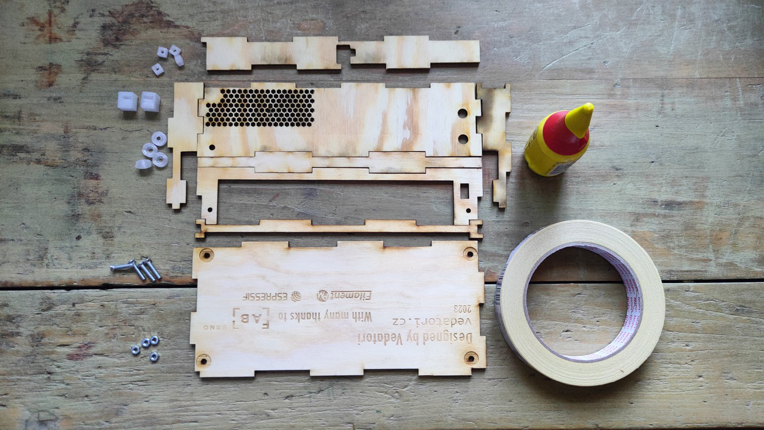
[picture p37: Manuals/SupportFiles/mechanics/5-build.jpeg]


## Kolik lepidla nanést:
Pokud je množství lepidla správné, mělo by po stlačení dílů trošku vytéct. Vymáčknuté lepidlo otřete papírovým ubrouskem.

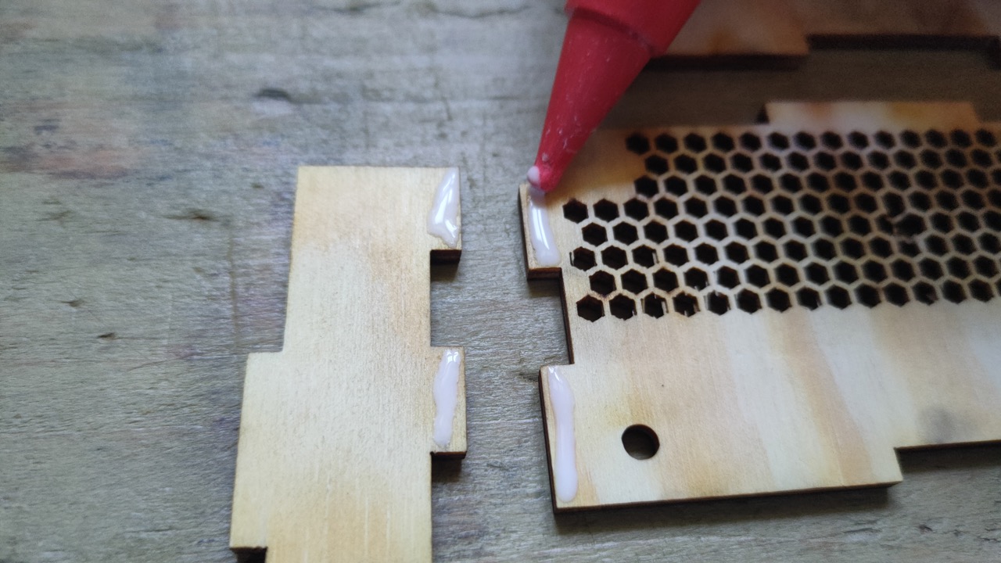
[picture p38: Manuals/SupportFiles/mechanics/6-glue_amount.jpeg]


## Postup:
Položte si vrchní překližkový díl na stůl a přilepte k němu zadní levou a pravou stranu krabičy. Vždy lepidlo naneste na všechny spojované plochy, tj. včetně ploch mezi jednotlivými stranami. Slepený spoj poté dočasně zpevněte kouskem papírové pásky.
Spodní díl krabičky se nelepí, můžete ho ale využít k zarovnání lepených dílů.

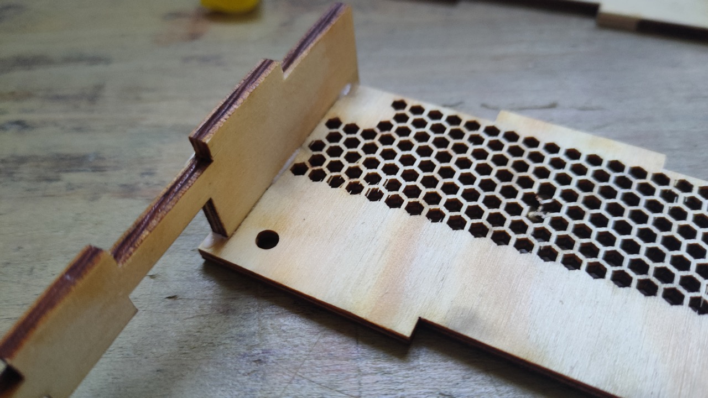
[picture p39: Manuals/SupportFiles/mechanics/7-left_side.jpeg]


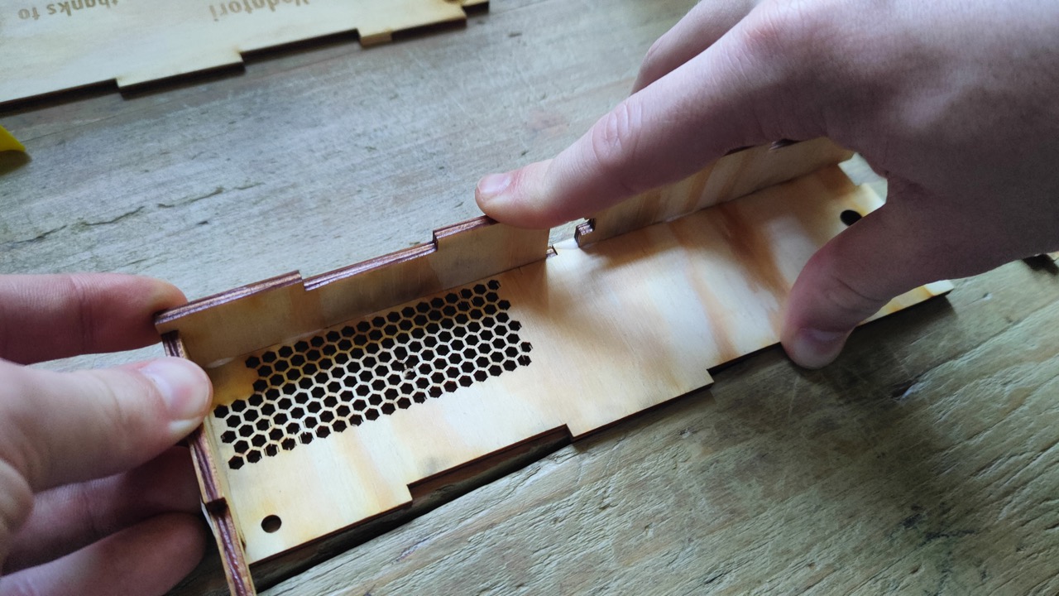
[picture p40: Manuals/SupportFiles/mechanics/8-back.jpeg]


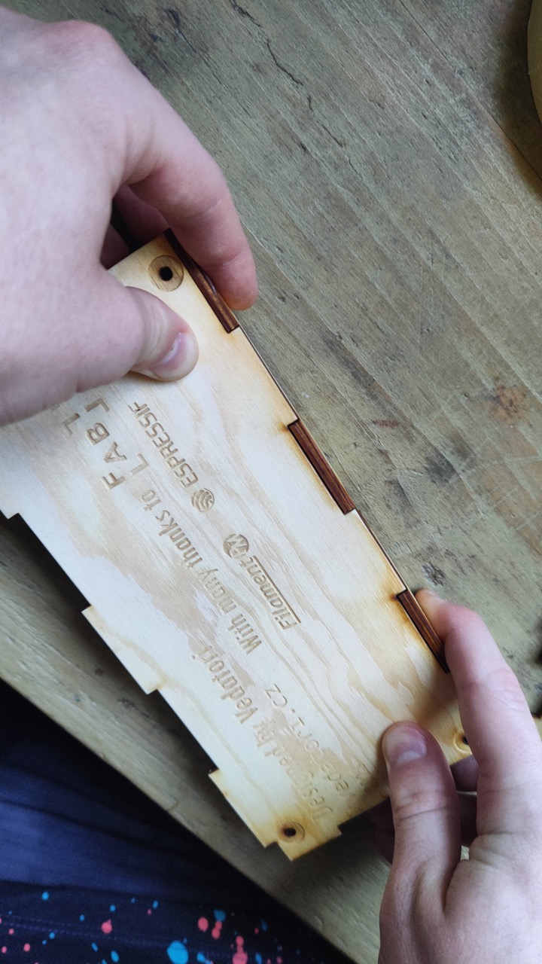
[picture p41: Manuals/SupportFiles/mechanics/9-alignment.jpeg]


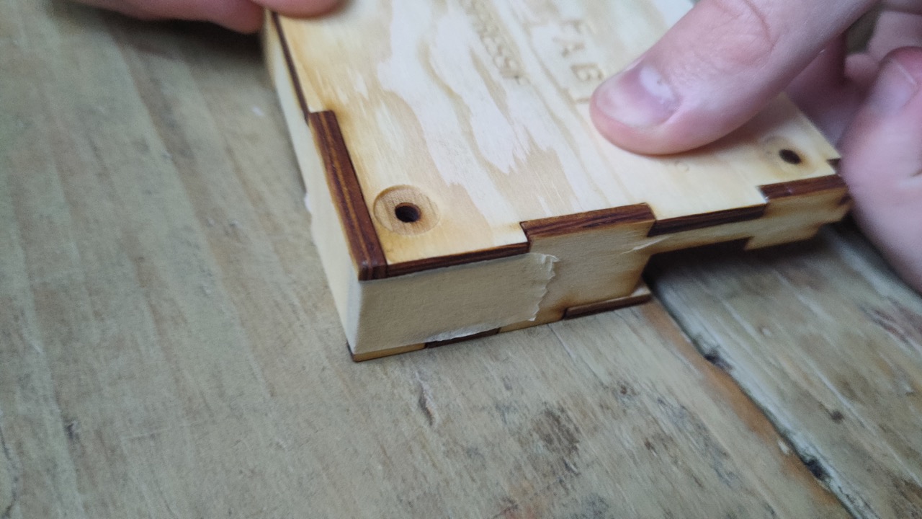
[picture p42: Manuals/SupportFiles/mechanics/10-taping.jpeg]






Přilepte přední překližkový díl a zafixujte ho lepící páskou. Pozor tento díl musí být k vrchní straně krabičky pečlivě přitisknutý, jinak krabička půjde špatně složit.



Vlepte kryt PCB. Vsuňte jej do krabičky pod úhlem co nejhlouběji a poté ho zamáčkněte dolů.









Přilepte druhý přední díl a zafixujte ho lepící páskou.



Do 2 nožiček zamáčkněte matku.

Vložte matky do dílů pro upevnění PCB a dna krabičky.



Vlepte s pomocí vedoucího epoxidem díly pro upevnění dna krabičky. Pozor nejsou stejné a záleží na umístění.



# <a name = lak>lakování krabičky</a>
## Potřebujeme:
* Slepená horní část krabičky
* Dno krabičky
* Jemný smirkový papír (600 - černý)
* Polyuretanový lak
* Štětec
* Miska s vodou

## Postup:
Sundejte z krabice všechny pásky, které jste použili při lepení. Natřete vnější plochy krabičky. Nechte ji uschnout tak, aby se natřené části nedotýkaly podložky (něčím krabičku podepřete). Štětcem setřete přebytečný lak, který se usadil na hranách. 

Štětec po dokončení lakování okamžitě ponořte do vody a vymyjte.

Převědčte se, že první vrstva laku je vytvrzená. Pokud ano, přebrušte lakované plochy. Většinou stačí méně než 10 tahů po každé ploše. 

Přejeďte čistým prstem po vybroušeném povrchu a přesvědčte se, že je hladký.

Přebroušené povrchy nalakujte druhou vrstvou laku. Lak nechte vyschnout tak, aby se lakované části nedotýkaly podkladu (jako minule).

Štětec po dokončení lakování okamžitě ponořte do vody a vymyjte.

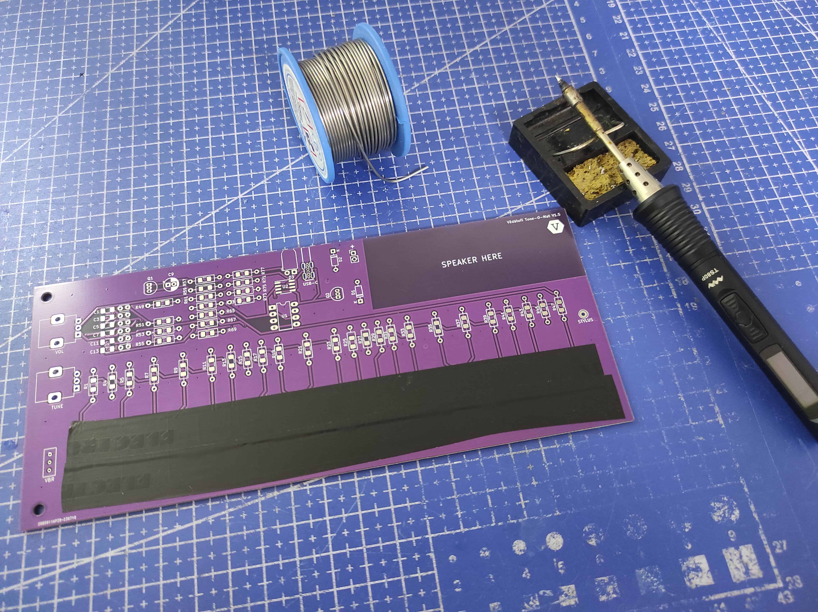
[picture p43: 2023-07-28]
Manuals/SupportFiles/startSoldering.jpg

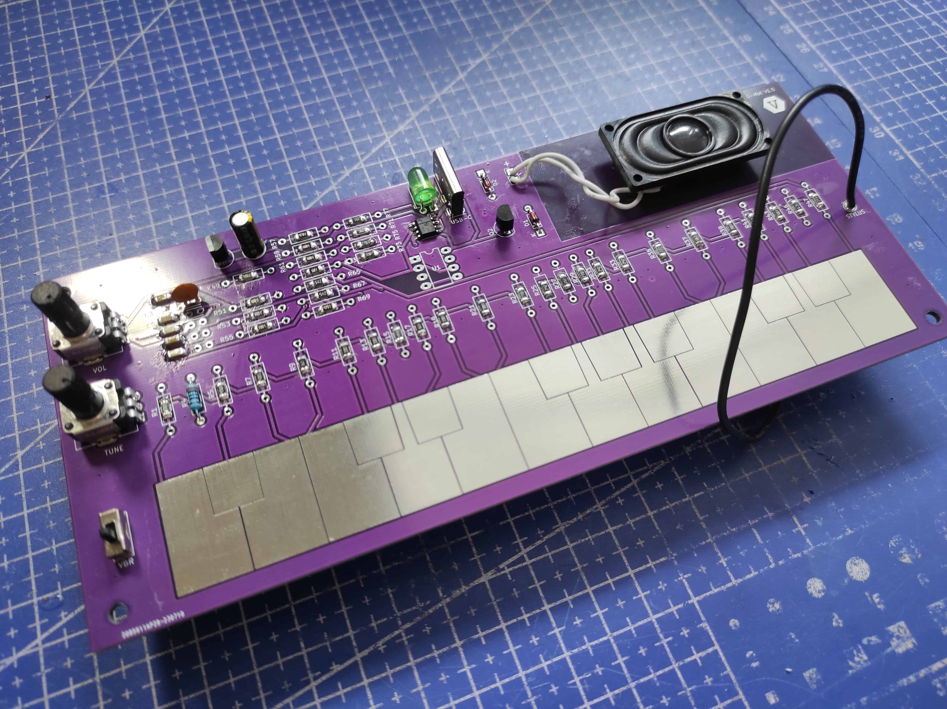
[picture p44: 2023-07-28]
Manuals/SupportFiles/finishedBoard.jpg

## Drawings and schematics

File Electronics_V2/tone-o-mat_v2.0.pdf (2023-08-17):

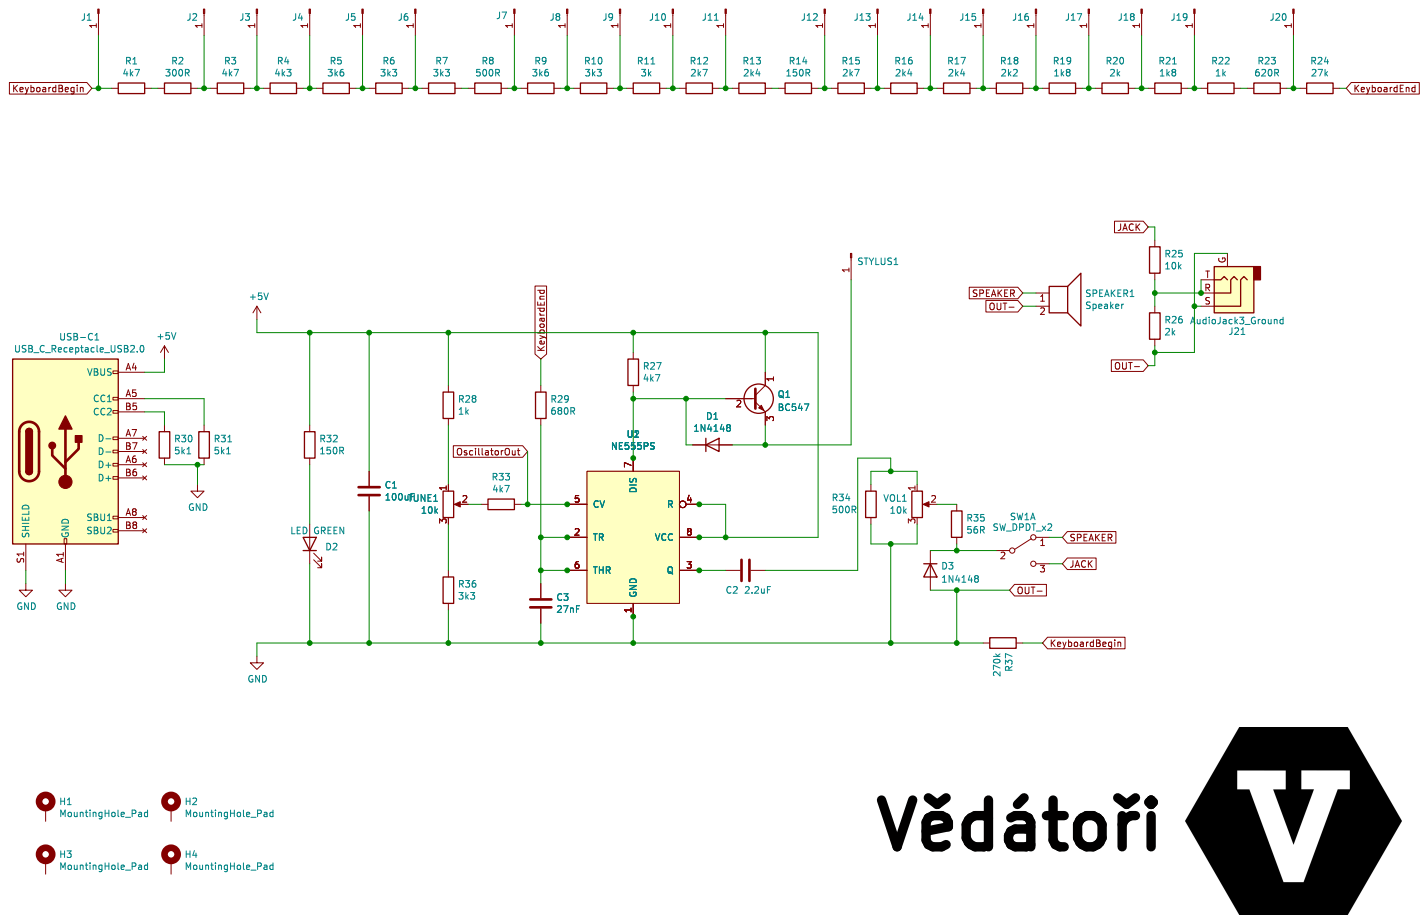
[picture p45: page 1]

SPEAKER OUT- OUT- KeyboardBegin KeyboardEnd

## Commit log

2023-01-25 Initial commit with basic schematic.
    [tone-o-mat.kicad_pcb, tone-o-mat.sch]
2023-01-25 First iteration of PCB.
    [tone-o-mat.sch]
2023-01-26 moved SMD 555
    [tone-o-mat.kicad_pcb]
2023-01-29 Kicad 6 verze. Nové USB-C a pěknější zarovnání klávesnice. TODO: Antiparalelní schottky dioda k reproduktoru, nezapomenout na silnější trasy!
    [tone-o-mat.kicad_pcb, tone-o-mat.kicad_sch, tone-o-mat.sch]
2023-02-26 Antiparalení dioda, naroutované trasy, spravené chybné footprinty a orientace součástek.
    [tone-o-mat.kicad_pcb, tone-o-mat.kicad_sch]
2023-04-14 USB C konektor s 0.6mm drill, aby deska šla vyrobit.
    [tone-o-mat.kicad_pcb]
2023-05-20 Nová verze 1.3, klávesnice správným směrem, nové schéma oscilátoru, otočené přepínače a změněné některé footprinty. Komplětně překopané rozložení součástek, ale rozměry desky zůstaly totožné.
    [tone-o-mat.kicad_pcb, tone-o-mat.kicad_sch]
2023-05-27 Updated servo PCB
    [tone-o-mat.kicad_pcb]
2023-06-06 Updates to board; changed footprint for switches, volume potentiometer moved farther right, some resistor alues were divided into two separate resistors.
    [tone-o-mat.kicad_pcb, tone-o-mat.kicad_sch]
2023-06-07 Made board smaller, without vibrato and power switch. Added power LED.
    [tone-o-mat.kicad_pcb, tone-o-mat.kicad_sch]
2023-06-24 Final board design. Added PWR LED, both potentiometers same footprint, removed PWR switch.
    [tone-o-mat.kicad_pcb, tone-o-mat.kicad_sch]
2023-07-01 Upraveno DRC finální desky.
    [tone-o-mat.kicad_pcb]
2023-07-03 DRC no clearance errors for final board.
    [tone-o-mat.kicad_pcb]
2023-07-27 Fixed oscillator problem and made parallel resistor to volume potentiometer. Also fixed some minor cosmetic issues.
    [bom.csv, designators.csv, positions.csv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]
2023-07-28 First version of the manual.
    [Tone-o-mat_BOM.csv, tables.xlsx, tone-o-mat.kicad_pcb]
2023-07-28 Updated manual to not include step numbering.
    [tables.xlsx]
2023-08-12 Added forgotten resistor to electronics manual.
2023-08-13 Added stylus step in electronics manual, rearranged resistor table.
2023-08-17 Made V2 electronics: with jack output, removed vibrato, made board dimensions pretty, added fourth hole.
    [tone-o-mat_v2.0.kicad_pcb, tone-o-mat_v2.0.kicad_sch]
2023-08-17 Added text on board, images in README.
    [tone-o-mat_v2.0.kicad_pcb, tone-o-mat_v2.0.kicad_sch]
2023-08-17 Replaced 3pin connector with audio-jack barrel.
    [tone-o-mat_v2.0.kicad_pcb, tone-o-mat_v2.0.kicad_sch]
2023-08-17 Grounded USB-C shield and remade gerbers.
    [tone-o-mat_v2.0.kicad_pcb]
2023-08-17 Added colorcoding for THT resistors in manual.
2023-08-17 Added capacitor imge to electronics manual.
2023-08-18 Added smd capacitor reference image to manual and edited 2k4 rezistor reference image..
